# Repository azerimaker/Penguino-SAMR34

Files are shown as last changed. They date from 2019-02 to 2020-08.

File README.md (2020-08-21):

# Penguino Feather LoRa development board
This repo contains all the necessary design and fabrication files for the Penguino radio module and its @Adafruit Father style breakout board. First prototype batch is being sold on my [Tindie](https://www.tindie.com/products/16985/) store.

### Penguino Feather v1.1:
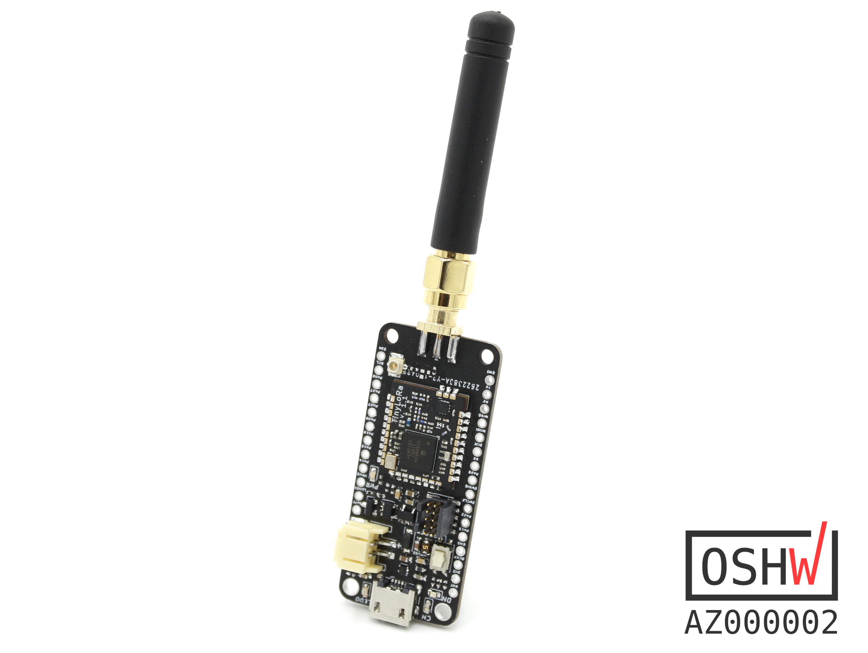
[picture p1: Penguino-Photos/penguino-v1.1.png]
Penguino Feather Breakout v1.1


## Penguino RF Module v1.2 Specs:
- [ATSAMR34J18](http://ww1.microchip.com/downloads/en/DeviceDoc/SAMR34-R35-Low-Power-LoRa-Sub-GHz-SiP-Data-Sheet-DS70005356B.pdf) LoRA System-in-Package (SiP) based RF module
- ARM Cortex M0+ MCU & LoRa Radio
- 256KB Flash, 40 KB RAM
- Power Output: 20.00(dBm) (DS value, real output is not tested)
- Frequency Range: 862 to 1020 MHz (DS values)
- Sleep Current: ~810 nA 
- IO pins: 27
- Module Dimenions: ~16.5x14x2 mm

### Penguino RF Module v1.1:
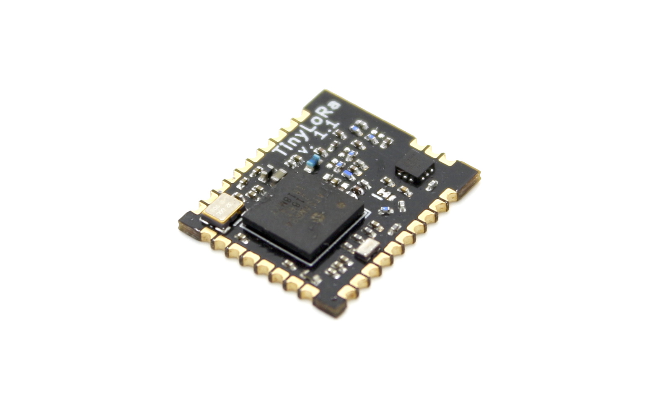
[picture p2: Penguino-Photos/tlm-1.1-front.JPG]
TLM01 v1 front

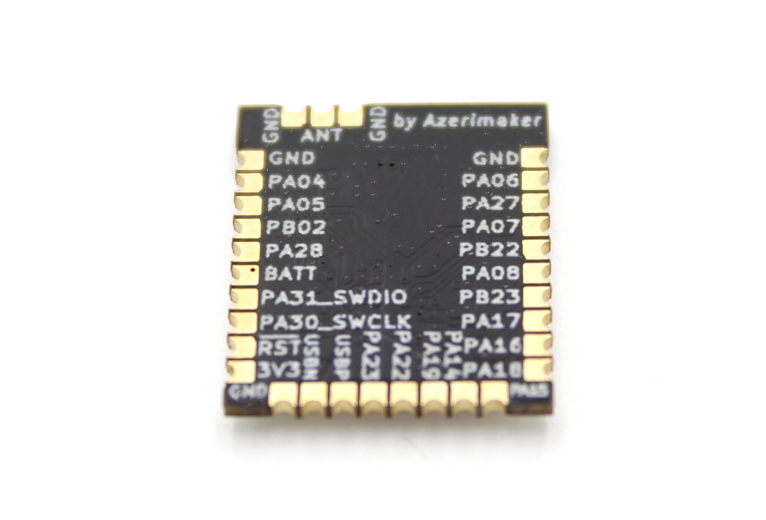
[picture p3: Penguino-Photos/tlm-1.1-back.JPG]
TLM01 v1 back

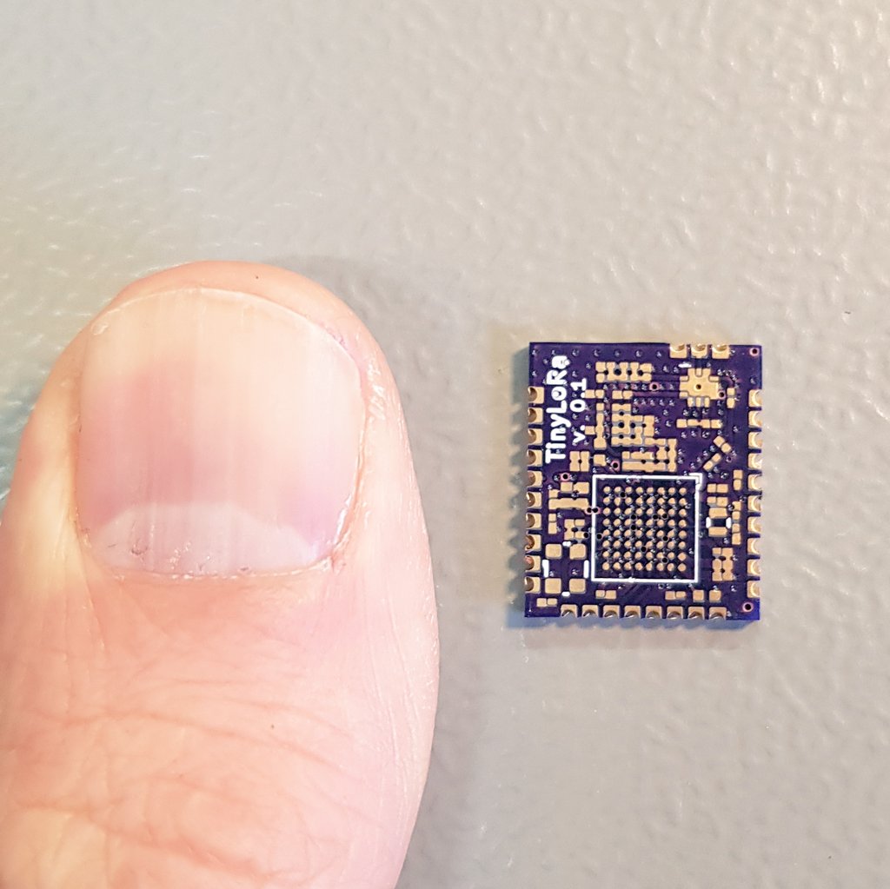
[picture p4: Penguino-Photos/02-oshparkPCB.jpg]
TLM01 v1 OSHpark PCB


### Penguino Feather v1.1 Blinky:
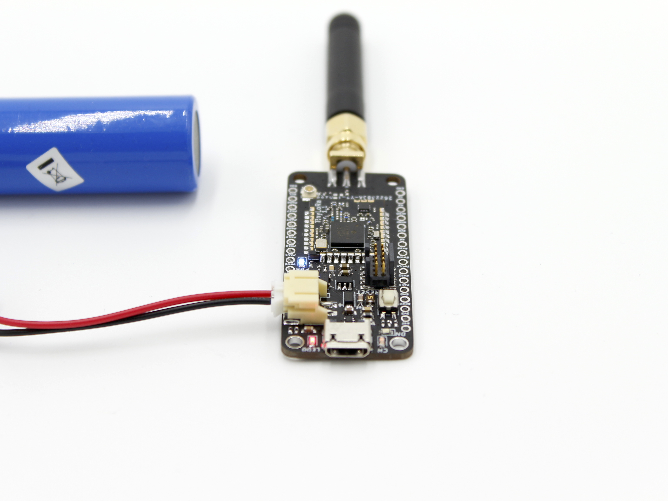
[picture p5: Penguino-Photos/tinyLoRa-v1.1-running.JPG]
TLM01 v1 first prototypes


License:
- Hardware license: CERN-OHL-S v2
- Software license: under MIT unless otherise indicated 
- Documentation license:  CC BY-SA 4.0 International.

________________________________
## Open Source Hardware
This board is an OSHWA approved design: [AZ000002](https://certification.oshwa.org/az000002.html)

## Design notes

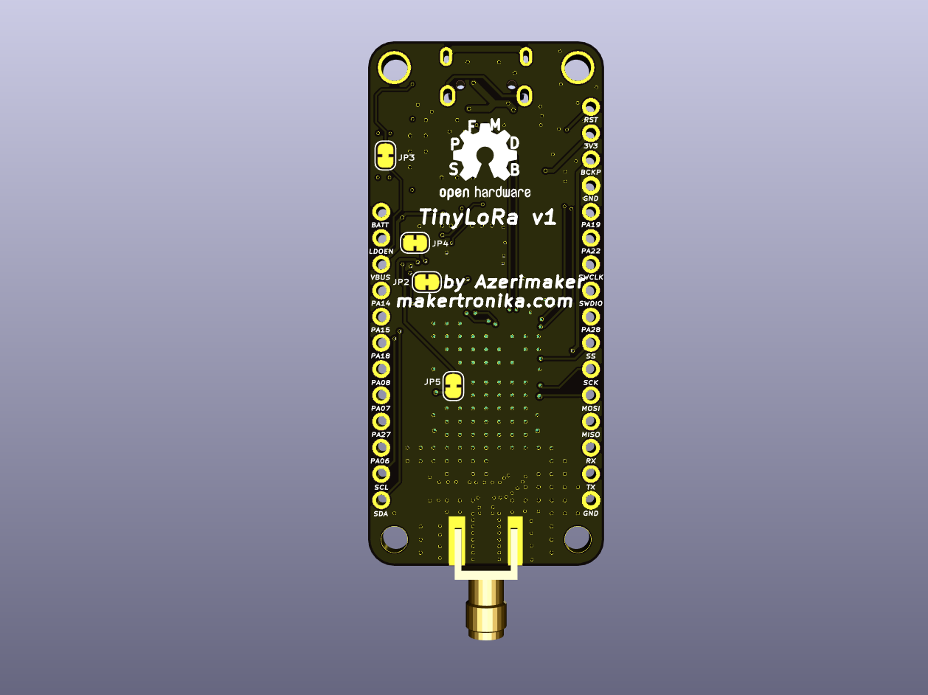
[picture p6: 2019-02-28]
Penguino-Photos/TLM01-breakout-v1-02.png

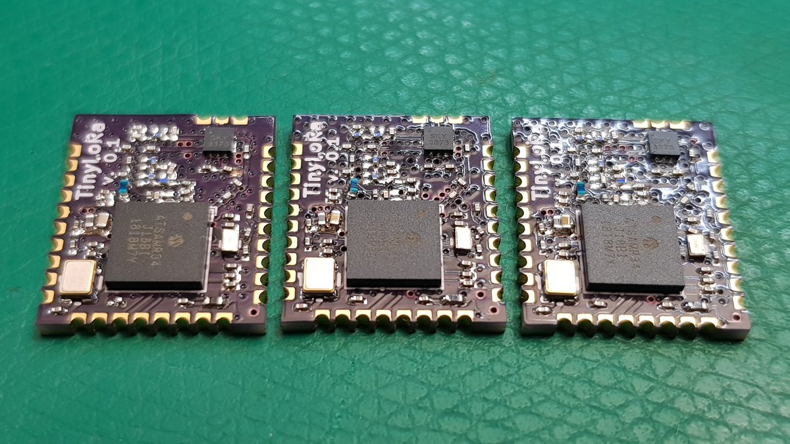
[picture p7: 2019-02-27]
Penguino-Photos/01-firstPrototyes.jpg

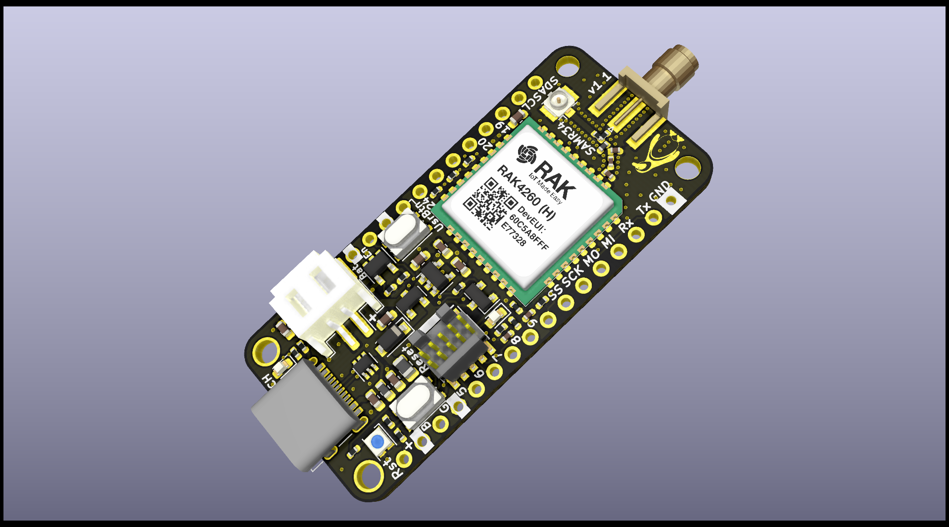
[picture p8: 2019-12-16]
Penguino-Photos/Penguino-Feather-4260-v1.1-3.png

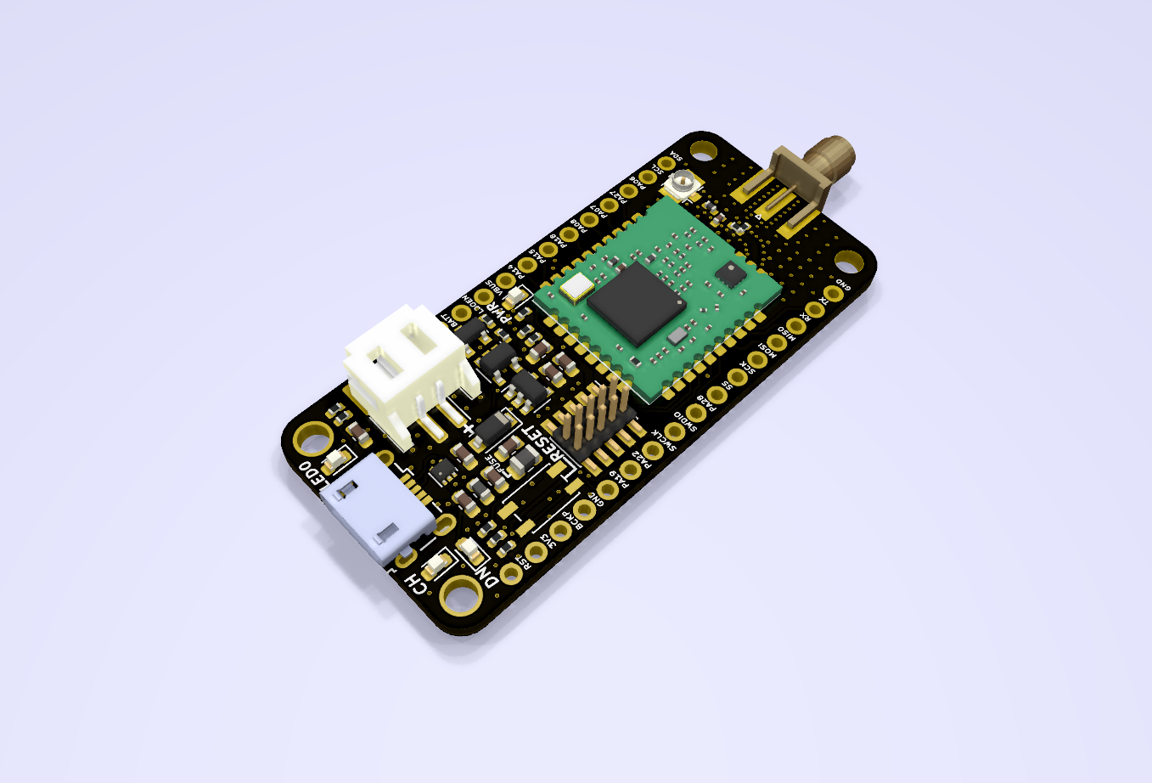
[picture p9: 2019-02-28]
Penguino-Photos/TLM01-breakout-v1-03.png

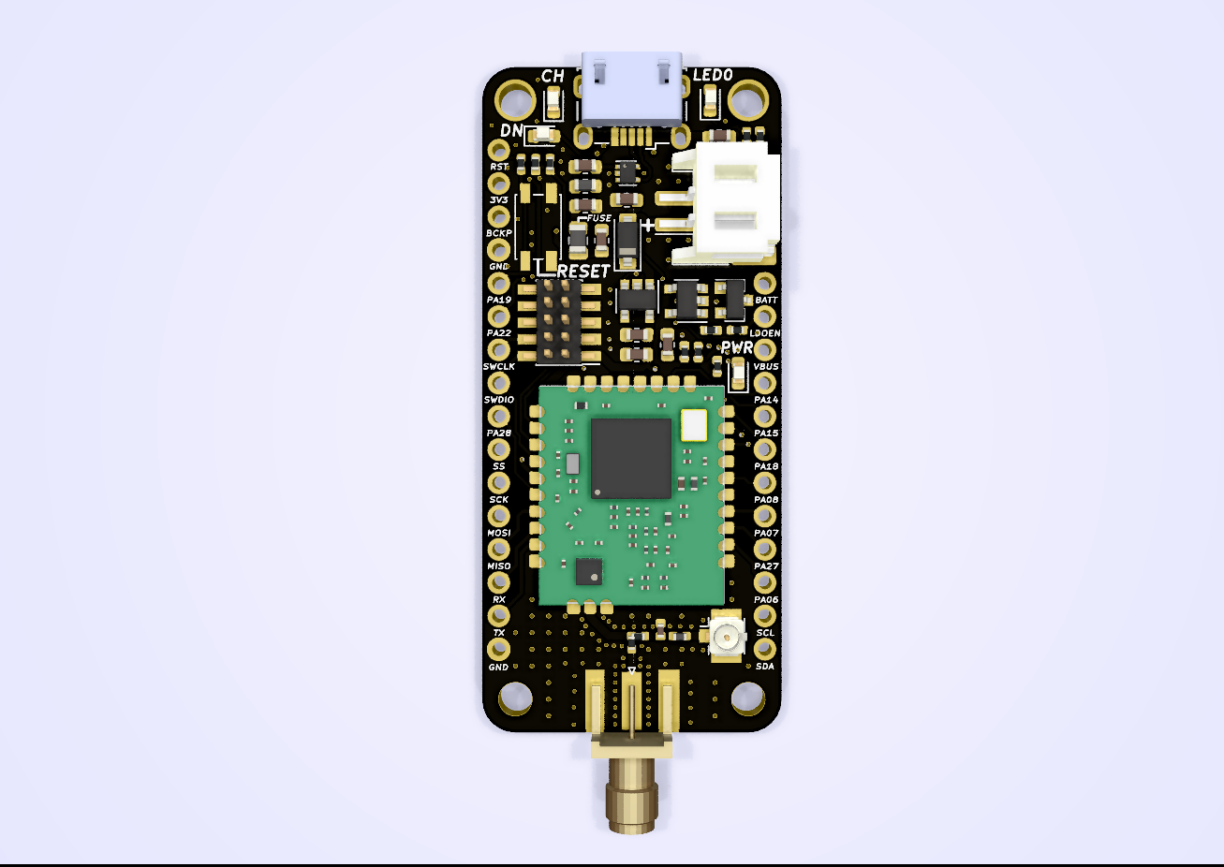
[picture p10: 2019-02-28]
Penguino-Photos/TLM01-breakout-v1-01.png

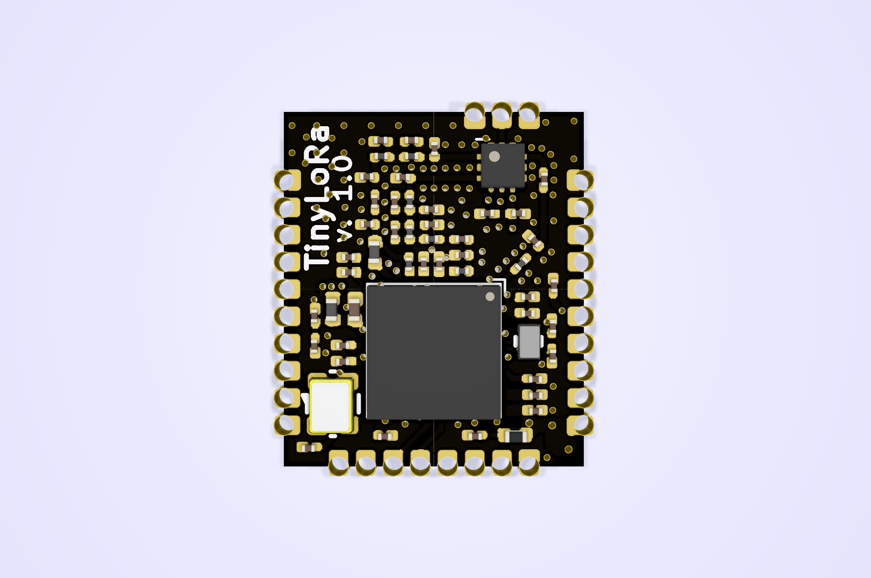
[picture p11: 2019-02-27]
Penguino-Photos/tlm-v1.0-render-front.png

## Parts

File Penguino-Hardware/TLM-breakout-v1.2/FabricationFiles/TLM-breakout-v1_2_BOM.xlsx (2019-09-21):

Name: | TLM01-breakout-v1.2
Date: | 23.06.2019
Tool: | KiCAD Eeschema 5.02
Total Component Count: |  | 34
Unique Component Count: |  | 27
Item # | Ref | Qnty | MPN | Description | Package | URL
1 | C3 C5 | 2 | CL10A106MO8NQNC | 10uF | Capacitor_SMD:C_0603_1608Metric | https://lcsc.com/product-detail/Multilayer-Ceramic-Capacitors-MLCC-SMD-SMT_SAMSUNG_CL10A106MO8NQNC_10uF-106-20-16V_C92487.html
2 | C4 | 1 | CC0603KRX7R8BB105 | 1uF | Capacitor_SMD:C_0603_1608Metric | https://lcsc.com/product-detail/Others_YAGEO-CC0603KRX7R8BB105_C106858.html
3 | C7 C9 | 2 | CC0603KRX7R9BB104 | 100nF | Capacitor_SMD:C_0603_1608Metric | https://lcsc.com/product-detail/Multilayer-Ceramic-Capacitors-MLCC-SMD-SMT_100nF-104-10-50V_C14663.html
4 | C8 C6 | 2 | CC0603KRX7R9BB103 | 10nF | Capacitor_SMD:C_0603_1608Metric | https://lcsc.com/product-detail/Multilayer-Ceramic-Capacitors-MLCC-SMD-SMT_10nF-103-10-50V_C100042.html
5 | D1 | 1 | MBR0520 | MBR0520 | Diode_SMD:D_SOD-123 | https://lcsc.com/product-detail/Schottky-Barrier-Diodes-SBD_Changjiang-Electronics-Tech-CJ-MBR0520_C77335.html
6 | D2 | 1 | 19-217/S2C-AL1M2VY/3T | CH_ORANGE | LED_SMD:LED_0603_1608Metric | https://lcsc.com/product-detail/Others_Everlight-Elec-19-217-S2C-AL1M2VY-3T_C264477.html
7 | D4 | 1 | FC-DA1608BK-470H10 | LED_PWR_BLUE | LED_SMD:LED_0603_1608Metric | https://lcsc.com/product-detail/Light-Emitting-Diodes-LED_Blue-light-SMDLED-80-100mcdatIF-10mA_C84266.html
8 | D5 | 1 | 19-217/R6C-AL1M2VY/3T | LED0_RED | LED_SMD:LED_0603_1608Metric | https://lcsc.com/product-detail/Light-Emitting-Diodes-LED_0603-Red-LED_C72044.html
9 | F1 | 1 | 0805L150SLYR | 1.5A | Fuse_0805_2012Metric | https://lcsc.com/product-detail/Surface-Mount-Fuses_Littelfuse_0805L150SLYR_Littelfuse-0805L150SLYR_C207025.html
10 | FB1 | 1 | BLM18HE152SN1D | BLM18HE152SN1D | Inductor_SMD:L_0603_1608Metric | https://lcsc.com/product-detail/Ferrite-Beads-And-Chips_muRata_BLM18HE152SN1D_1-5KR-25-at100MHz_C82155.html
11 | J1 | 1 | SMA-J-P-H-ST-EM1 | SMA-Edge-Mount | SMA_J_P_X_ST_EM1_EdgeMount | https://www.aliexpress.com/item/-/32953890440.html?spm=a2g0o.cart.0.0.6e6b3c00W25ze0
12 | J2 | 1 | U.FL-R-SMT-1(80) | U.FL-R-SMT-1 | U.FL_Hirose_U.FL-R-SMT-1_Vertical | https://lcsc.com/product-detail/_Hirose_U-FL-R-SMT-1-80_Hirose-HRS-U-FL-R-SMT-1-80_C88374.html
13 | J3 | 1 | S2B-PH-SM4-TB(LF)(SN) | JST_PH | JST_PH_S2B-PH-SM4-TB_1x02-1MP_P2.00mm_Horizontal | https://www.digikey.de/product-detail/de/jst-sales-america-inc/S2B-PH-SM4-TB-LF-SN/455-1749-1-ND/926846
14 | J4 | 1 | C10418 | USB_B_Micro | USB_Micro-B | https://lcsc.com/product-detail/USB-Connectors_Jing-Extension-of-the-Electronic-Co-LCSC-MICRO-USB-5S-B-Type-horns-High-temperature_C10418.html
15 | J5 | 1 | FTSH-105-01-F-DV-K | Cortex_JTAG_SWD_10pin | PinHeader_2x05_P1.27mm_Vertical_SMD | https://www.digikey.de/product-detail/de/samtec-inc/FTSH-105-01-F-DV-K-TR/SAM13160CT-ND/8827915
16 | R10 R11 | 2 | 0402WGF1004TCE | 1M | Resistor_SMD:R_0402_1005Metric | https://lcsc.com/product-detail/Chip-Resistor-Surface-Mount_Uniroyal-Elec-0402WGF1004TCE_C26083.html
17 | R12 | 1 | RC0402JR-073M6L | 3M6 | Resistor_SMD:R_0402_1005Metric | https://lcsc.com/product-detail/Chip-Resistor-Surface-Mount_3-6MR-365-5_C137871.html
18 | L1 R2 | 2 | RC0402JR-070RL | 0R | Resistor_SMD:R_0402_1005Metric | https://lcsc.com/product-detail/Chip-Resistor-Surface-Mount_0R-0R-5_C60485.html
19 | R4 | 1 | RC0402FR-074K7L | 4K7 | Resistor_SMD:R_0402_1005Metric | https://lcsc.com/product-detail/Chip-Resistor-Surface-Mount_4-7KR-4701-1_C105871.html
20 | R5 | 1 | RC0402JR-07100KL | 100K | Resistor_SMD:R_0402_1005Metric | https://lcsc.com/product-detail/Chip-Resistor-Surface-Mount_100KR-104-5_C106234.html
21 | R7 | 1 | RC0402JR-07100RL | 100R | Resistor_SMD:R_0402_1005Metric | https://lcsc.com/product-detail/Chip-Resistor-Surface-Mount_100R-101-5_C106233.html
22 | R9 R8 R6 | 3 | RC0402FR-071K5L | 1K5 | Resistor_SMD:R_0402_1005Metric | https://lcsc.com/product-detail/Chip-Resistor-Surface-Mount_1-5KR-1501-1_C114759.html
23 | SW3 | 1 | SKRPACE010 | RESET | SW_Push_SKRPACE010 | https://lcsc.com/product-detail/Tactile-Switches_ALPS_SKRPACE010_SKRPACE010_C139797.html
24 | U2 | 1 | TP4054 | or MCP73831 LiPo Charger IC | Package_TO_SOT_SMD:SOT-23-5 | https://lcsc.com/product-detail/PMIC-Battery-Management_TP4054_C32574.html
25 | U3 | 1 | MAX809STRG | 2.93V Voltage Supervisor | Package_TO_SOT_SMD:SOT-23 | https://lcsc.com/product-detail/PMIC-Supervisors_TI_TPS3839K33DBZR_TPS3839K33DBZR_C96333.html
26 | U4 | 1 | ME6215C33 | 3.3V LDO | Package_TO_SOT_SMD:SOT-23-5 | https://lcsc.com/product-detail/Low-Dropout-Regulators-LDO_ME6215C33M5G_C84119.html
27 | U5 | 1 | NUP2202W1T2G | NUP2202 | Package_TO_SOT_SMD:SOT-363_SC-70-6 | https://lcsc.com/product-detail/TVS_ON-Semicon_NUP2202W1T2G_ON-Semicon-ON-NUP2202W1T2G_C89322.html

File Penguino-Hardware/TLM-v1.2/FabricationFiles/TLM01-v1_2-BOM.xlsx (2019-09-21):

Name: | TLM01-v1.2 |  |  |  |  |  |  |  | Updates
Date: | 22.07.2019
Tool: | KiCAD Eeschema 5.02
Total Component Count: |  | 48
Unique Component Count: |  | 25
Item # | Ref | Qnty | MPN | Description | Package | Type | URL | ~
1 | C1 | 1 | GRM155R60J106ME15D | 10uF | _0402_1005Metric | SMD | https://www.mouser.de/ProductDetail/?qs=I53XXhTNm8s65u6%252BR3mHqw%3D%3D | ~
3 | C17 | 1 | GRM0335C1H180GA01D | 18pF | _0201_0603Metric | SMD | https://www.mouser.de/ProductDetail/?qs=3ZwS9AhGA%2F5E94CAvJ5D3g%3D%3D | ~
4 | C18 C29 | 2 | GRM0335C1H3R9BA01D | 3.9pF | _0201_0603Metric | SMD | https://www.mouser.de/ProductDetail/?qs=7vGxPDjevFPA4PAcLjuEQA%3D%3D | ~
5 | C19 C21 C32 | 3 | GJM0335C1E3R3BB01D | 3.3pF | _0201_0603Metric | SMD | https://www.mouser.de/ProductDetail/?qs=CDqEb46GNC4YtpMq7%2FbijA%3D%3D | ~
6 | C20 C31 | 2 | GRM0335C1E5R6BA01D | 5.6pF | _0201_0603Metric | SMD | https://www.mouser.de/ProductDetail/?qs=7vGxPDjevFO7ofteVuiOog%3D%3D | ~
7 | C22 | 1 | 250R05L470GV4T | 47pF | _0201_0603Metric | SMD | https://www.mouser.de/ProductDetail/?qs=qF3SSroohZVo%252BRycgwe6NA%3D%3D | ~
8 | C23 | 1 | GJM0335C1E2R7BB01J | 2.7pF | _0201_0603Metric | SMD | https://www.mouser.de/ProductDetail/?qs=YLLXL5qGyDu%252B5BvRK2mndA%3D%3D | ~
9 | C25 | 1 | GRM033R71A472KA01D | 4.7nF | _0201_0603Metric | SMD | https://www.mouser.de/ProductDetail/?qs=7RtWncwVCuzI4WvsbOl%2FQA%3D%3D | ~
10 | C28 | 1 | 02013A220GAT2A | 22pF | _0201_0603Metric | SMD | https://www.mouser.de/ProductDetail/?qs=8uxLZIVza1t02bPvhkkLOQ%3D%3D | ~
11 | C10 C11 C13 C14 C15 C2 C3 C35 C4 C5 C6 C8 C9 | 13 | 02016D104KAT2A | 100nF | _0201_0603Metric | SMD | https://www.mouser.de/ProductDetail/?qs=PN7sAUOUrntlfwxbZzo6OQ%3D%3D | ~
12 | C30 | 1 | GJM0335C1E8R2BB01D | 8.2pF | _0201_0603Metric | SMD | https://www.mouser.de/ProductDetail/?qs=ui%252B2d9lVEI5Br9X%2Fgsfs7g%3D%3D | ~
13 | C12 C33 | 2 | GJM0335C1E4R7CB01D | 4.7pF | _0201_0603Metric | SMD | https://www.mouser.de/ProductDetail/?qs=563MOeNa05LpxJEDDo5HXg%3D%3D | ~
14 | C34 | 1 | GRM033R71C102KA01J | 1nF | _0201_0603Metric | SMD | https://www.mouser.de/ProductDetail/?qs=563MOeNa05Lkaj9jkbLdjg%3D%3D | ~
15 | C36 C37 | 2 | ‎CC0201DRNPO8BN100‎ | 10pF | _0201_0603Metric | SMD | https://www.mouser.de/ProductDetail/?qs=tS%2FAHvPQ%2F57tl3WO6qJY3g%3D%3D | ~
16 | C7 | 1 | GRM0335C1E330JA01D | 33pF | _0201_0603Metric | SMD | https://www.mouser.de/ProductDetail/?qs=3ZwS9AhGA%2F56pkS80K8T0A%3D%3D | ~
17 | FB1 | 1 | BLM15AG121SN1D | Ferrite Beads 120 OHM LOW SPEED | _0402_1005Metric | SMD | https://www.mouser.de/ProductDetail/?qs=0mZ9c%252Bni6FbHnpaodfEgFg%3D%3D | ~
18 | L3 | 1 | LQW15AN2N2C10D | 2.2nH | _0402_1005Metric | SMD | https://www.mouser.de/ProductDetail/?qs=L0gQqYTeSd%252BvMGiveX8TBg%3D%3D | ~
19 | L10 L11 L4 L5 L7 | 5 | LQP03TN10NH02D | 10nH | _0201_0603Metric | SMD | https://www.mouser.de/ProductDetail/?qs=e%252BE4OD6MgMdNOh%2FUxJ4FMA%3D%3D | ~
20 | L6 L8 | 2 | L-05B33NJV6T | 33nH | _0201_0603Metric | SMD | https://www.mouser.de/ProductDetail/?qs=qF3SSroohZUDjNBhhoaXag%3D%3D | ~
21 | L9 | 1 | LQP03TQ11NJ02D | 11nH | _0201_0603Metric | SMD | https://www.mouser.de/ProductDetail/?qs=sEr9WmQGXZZzM50AKPJQwQ%3D%3D | ~
22 | R1 | 1 | RC0402JR-13100KL | 100K | _0402_1005Metric | SMD | https://www.mouser.de/ProductDetail/?qs=fPU49sp6fCKv5x2dIUTdvw%3D%3D | ~
24 | U2 | 1 | ATSAMR34J18BT-I/7JX | ATSAMR34J18BT | TFBGA-64_6.0x6.0_P0.65mm | SMD | https://www.mouser.de/ProductDetail/?qs=PqoDHHvF648Gm3bwnEWPBA%3D%3D | ~
25 | U3 | 1 | SKY13373-460LF | SKY13373-460LF | QFN-12-1EP_3x3mm_P0.5mm | SMD | https://www.mouser.de/ProductDetail/?qs=WMHGlxXAKT%252BCKwFkyhUcUQ%3D%3D | ~
26 | XC1 | 1 | ECS-TXO-2520-33-320-AN-TR | 32MHz TCXO Clipped Sine Wave Oscillator 2.8V ~ 3.3V 4-SMD, No Lead | Oscilator_2.5x2.0 | SMD | https://www.mouser.de/ProductDetail/?qs=KAq9QXcE8HADIhO7CEy%2FJw%3D%3D | ~
27 | Y1 | 1 | ABS05-32.768-kHz-9-T | ABS05-32.768KHZ-9-T | ABS05_32.768KHz Crystal | SMD | https://www.mouser.de/ProductDetail/?qs=Pyu0ZBy%2FIJbsNYnIET1z3A%3D%3D | ~

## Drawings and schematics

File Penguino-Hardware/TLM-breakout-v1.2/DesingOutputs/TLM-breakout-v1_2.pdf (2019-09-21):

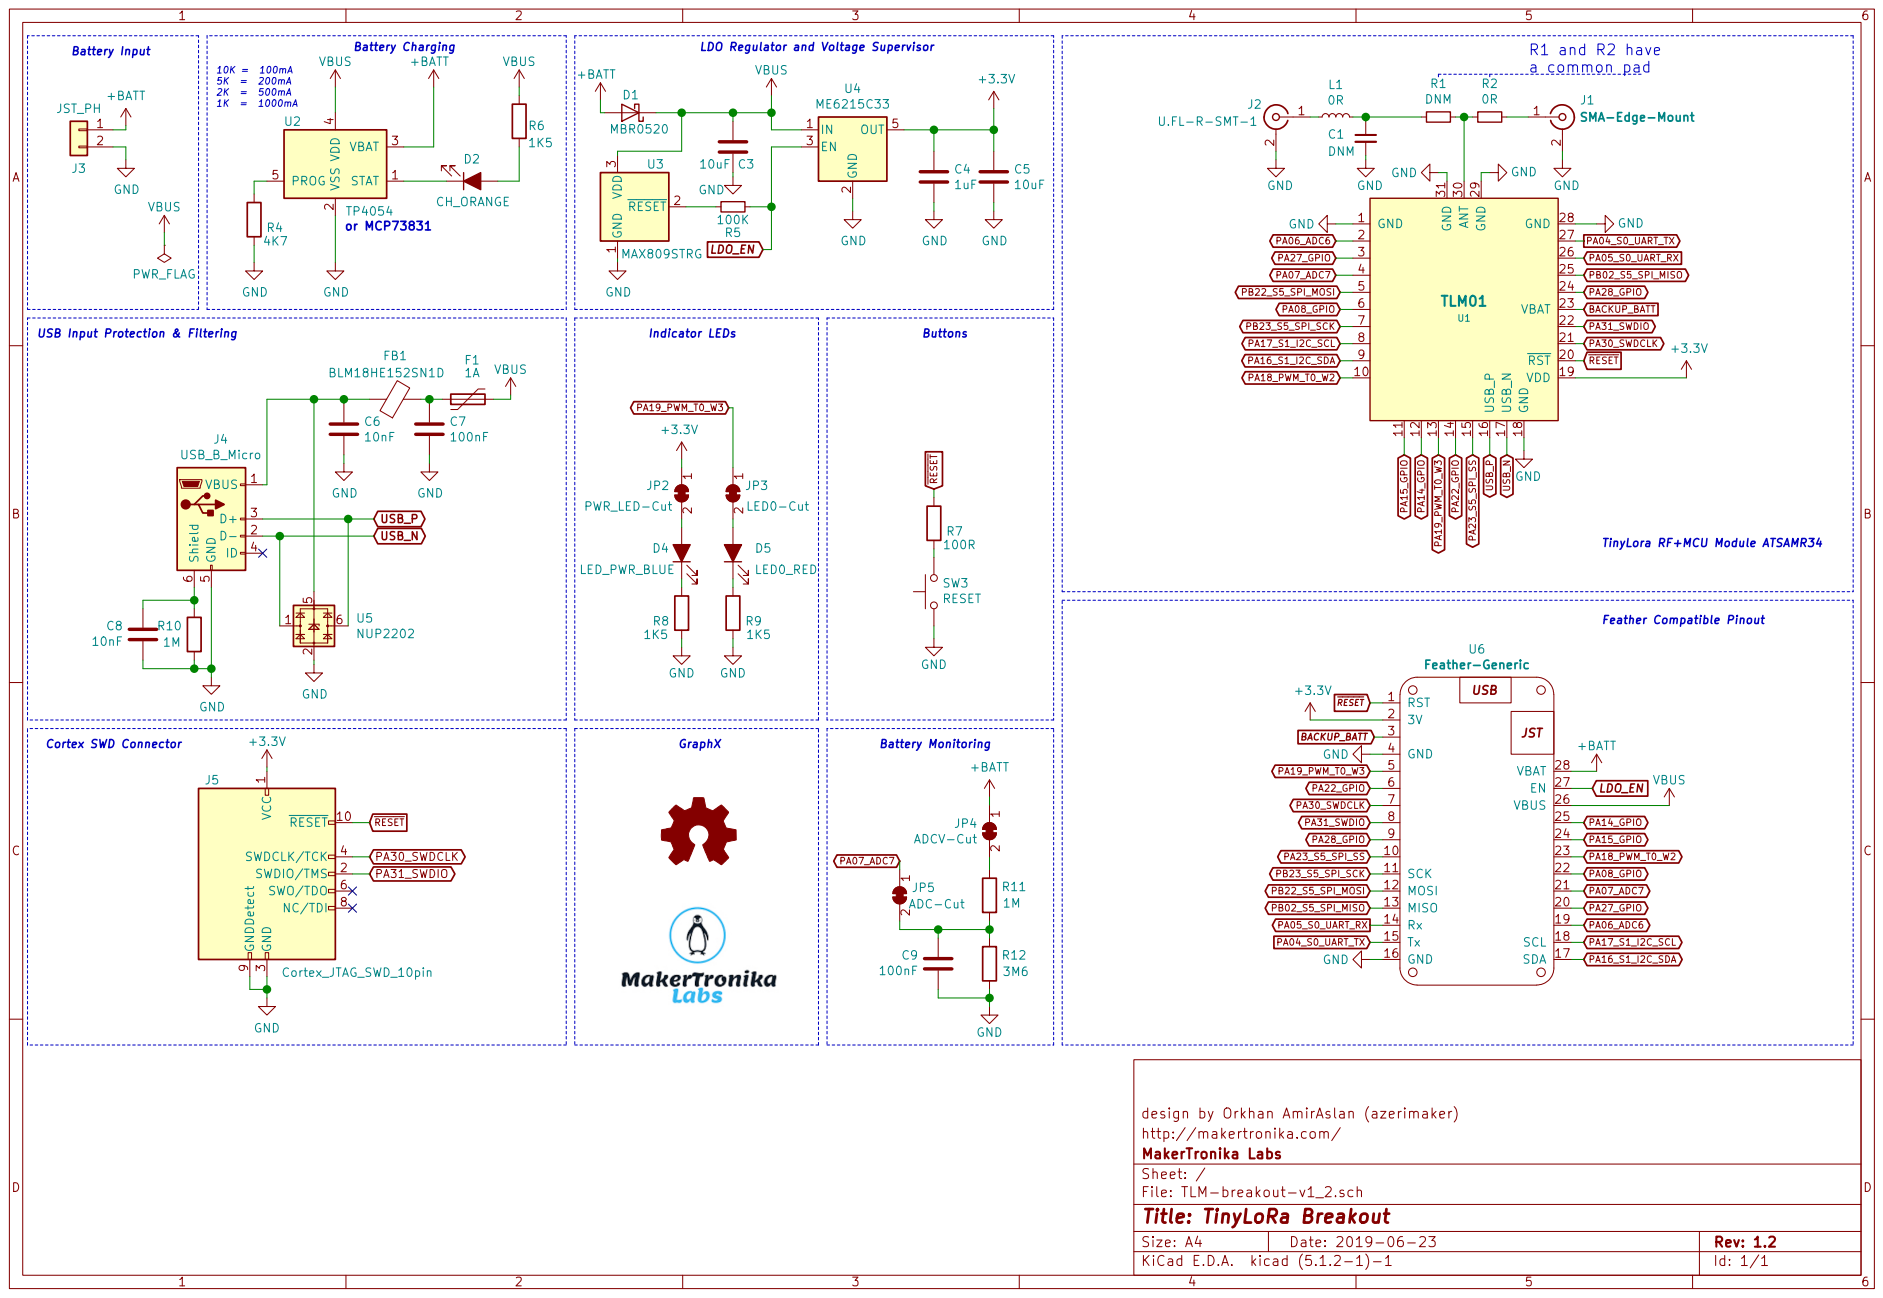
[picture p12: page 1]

2 EN 3 OUT 5 U4 ME6215C33 STAT 1 VSS

1 RESET 10 SWDIO/TMS 2 GND

3 SWDCLK/TCK 4 SWO/TDO 6 NC/TDI 8 GNDDetect 9

design by Orkhan AmirAslan (azerimaker)
http://makertronika.com/
File: TLM-breakout-v1_2.sch Sheet: / MakerTronika Labs

Id: 1/1 Title: TinyLoRa Breakout

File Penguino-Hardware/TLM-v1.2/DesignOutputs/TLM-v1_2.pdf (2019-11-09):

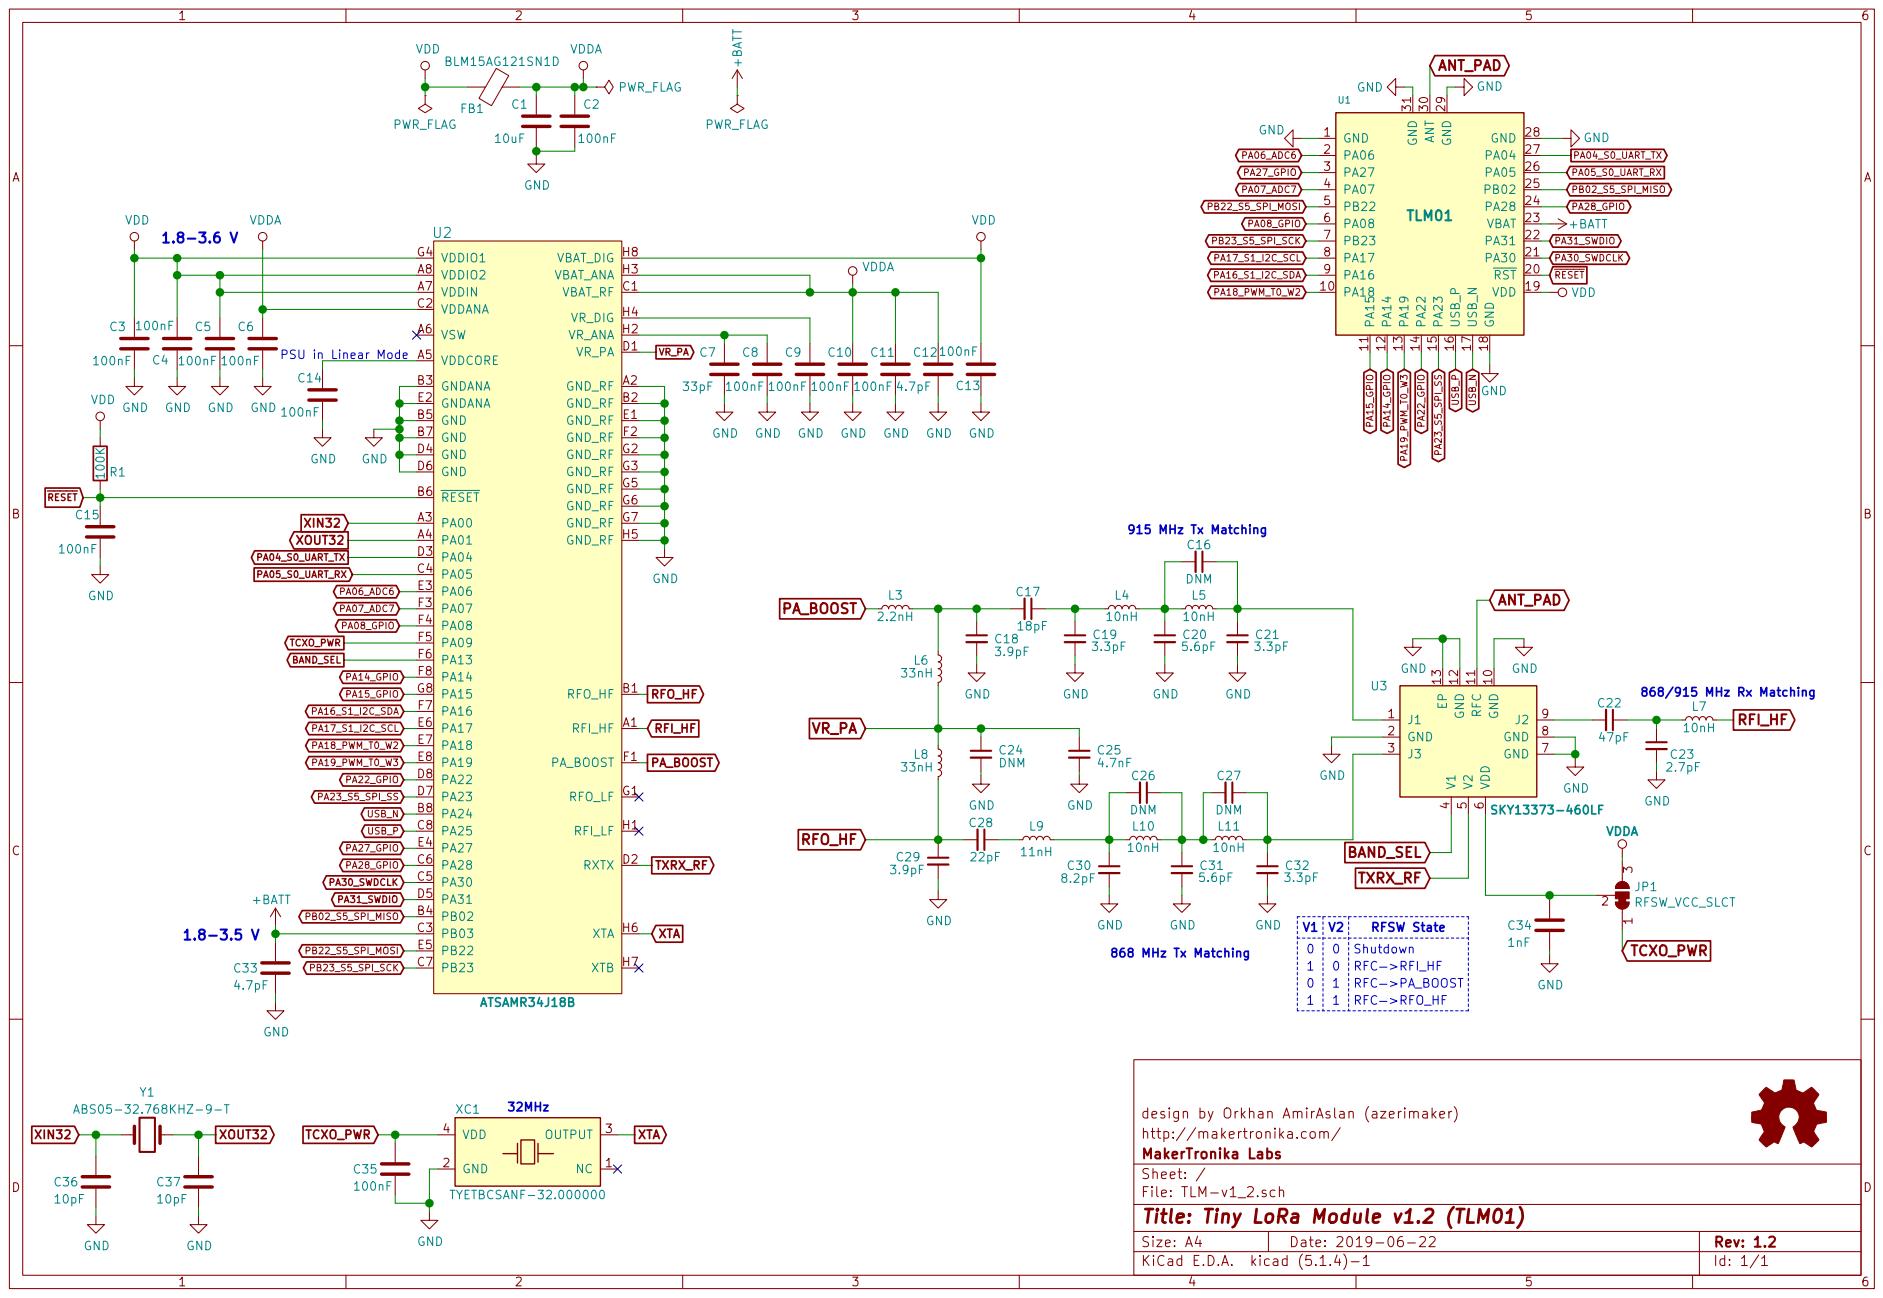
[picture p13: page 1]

design by Orkhan AmirAslan (azerimaker) L6

0 | 0 | Shutdown RFSW State

1 1 | 0 1 1 | RFC>RFO_HF RFC>PA_BOOST RFC>RFI_HF

http://makertronika.com/
File: TLM-v1_2.sch Sheet: / MakerTronika Labs

Id: 1/1 Title: Tiny LoRa Module v1.2 (TLM01)

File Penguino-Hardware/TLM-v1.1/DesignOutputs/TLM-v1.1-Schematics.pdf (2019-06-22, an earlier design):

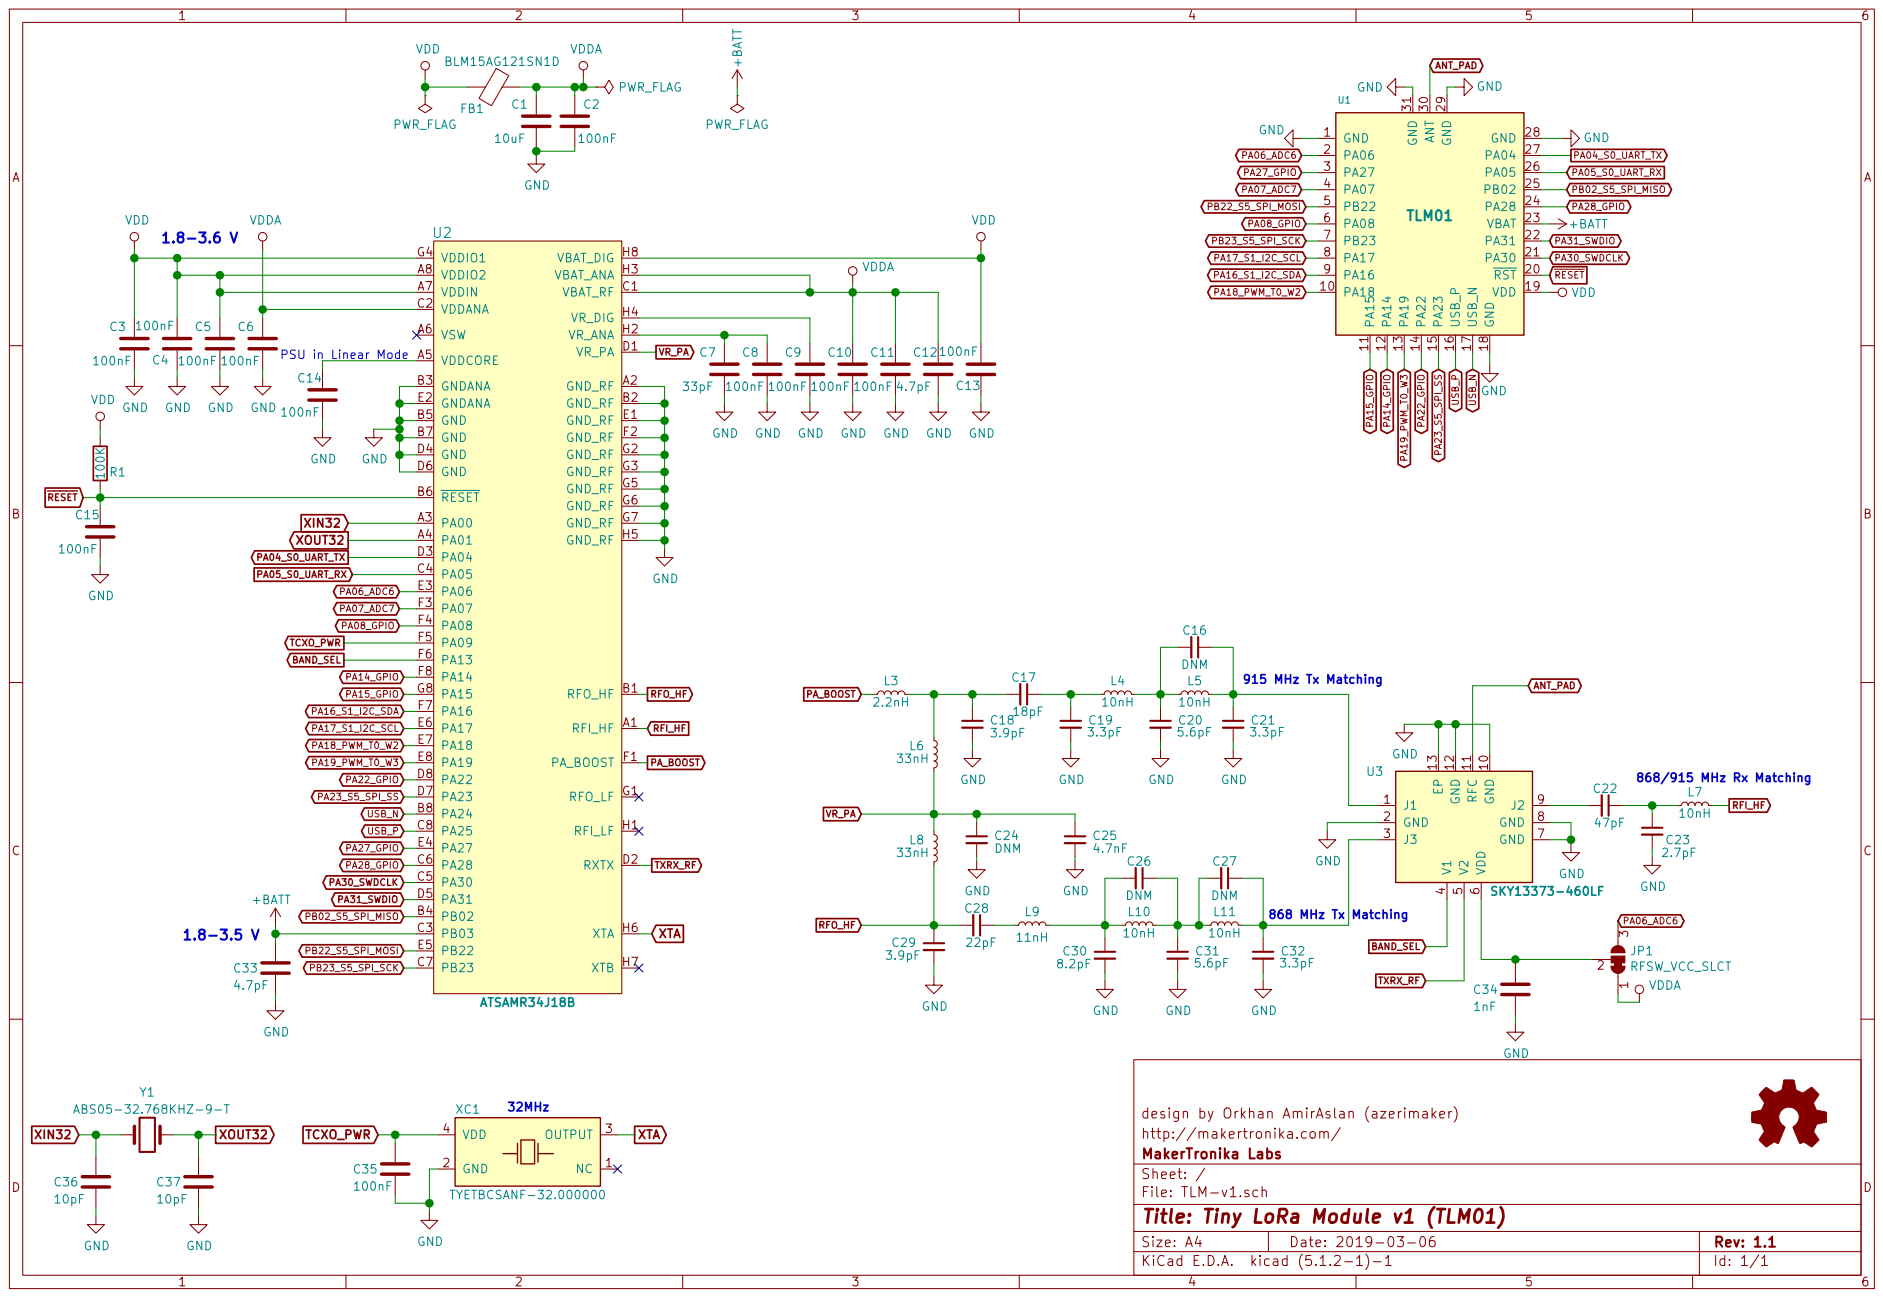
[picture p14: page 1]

PSU in Linear Mode C33

4.7pF GND GND GND GND GND GND GND

http://makertronika.com/
Id: 1/1 Title: Tiny LoRa Module v1 (TLM01) File: TLM-v1.sch Sheet: / MakerTronika Labs

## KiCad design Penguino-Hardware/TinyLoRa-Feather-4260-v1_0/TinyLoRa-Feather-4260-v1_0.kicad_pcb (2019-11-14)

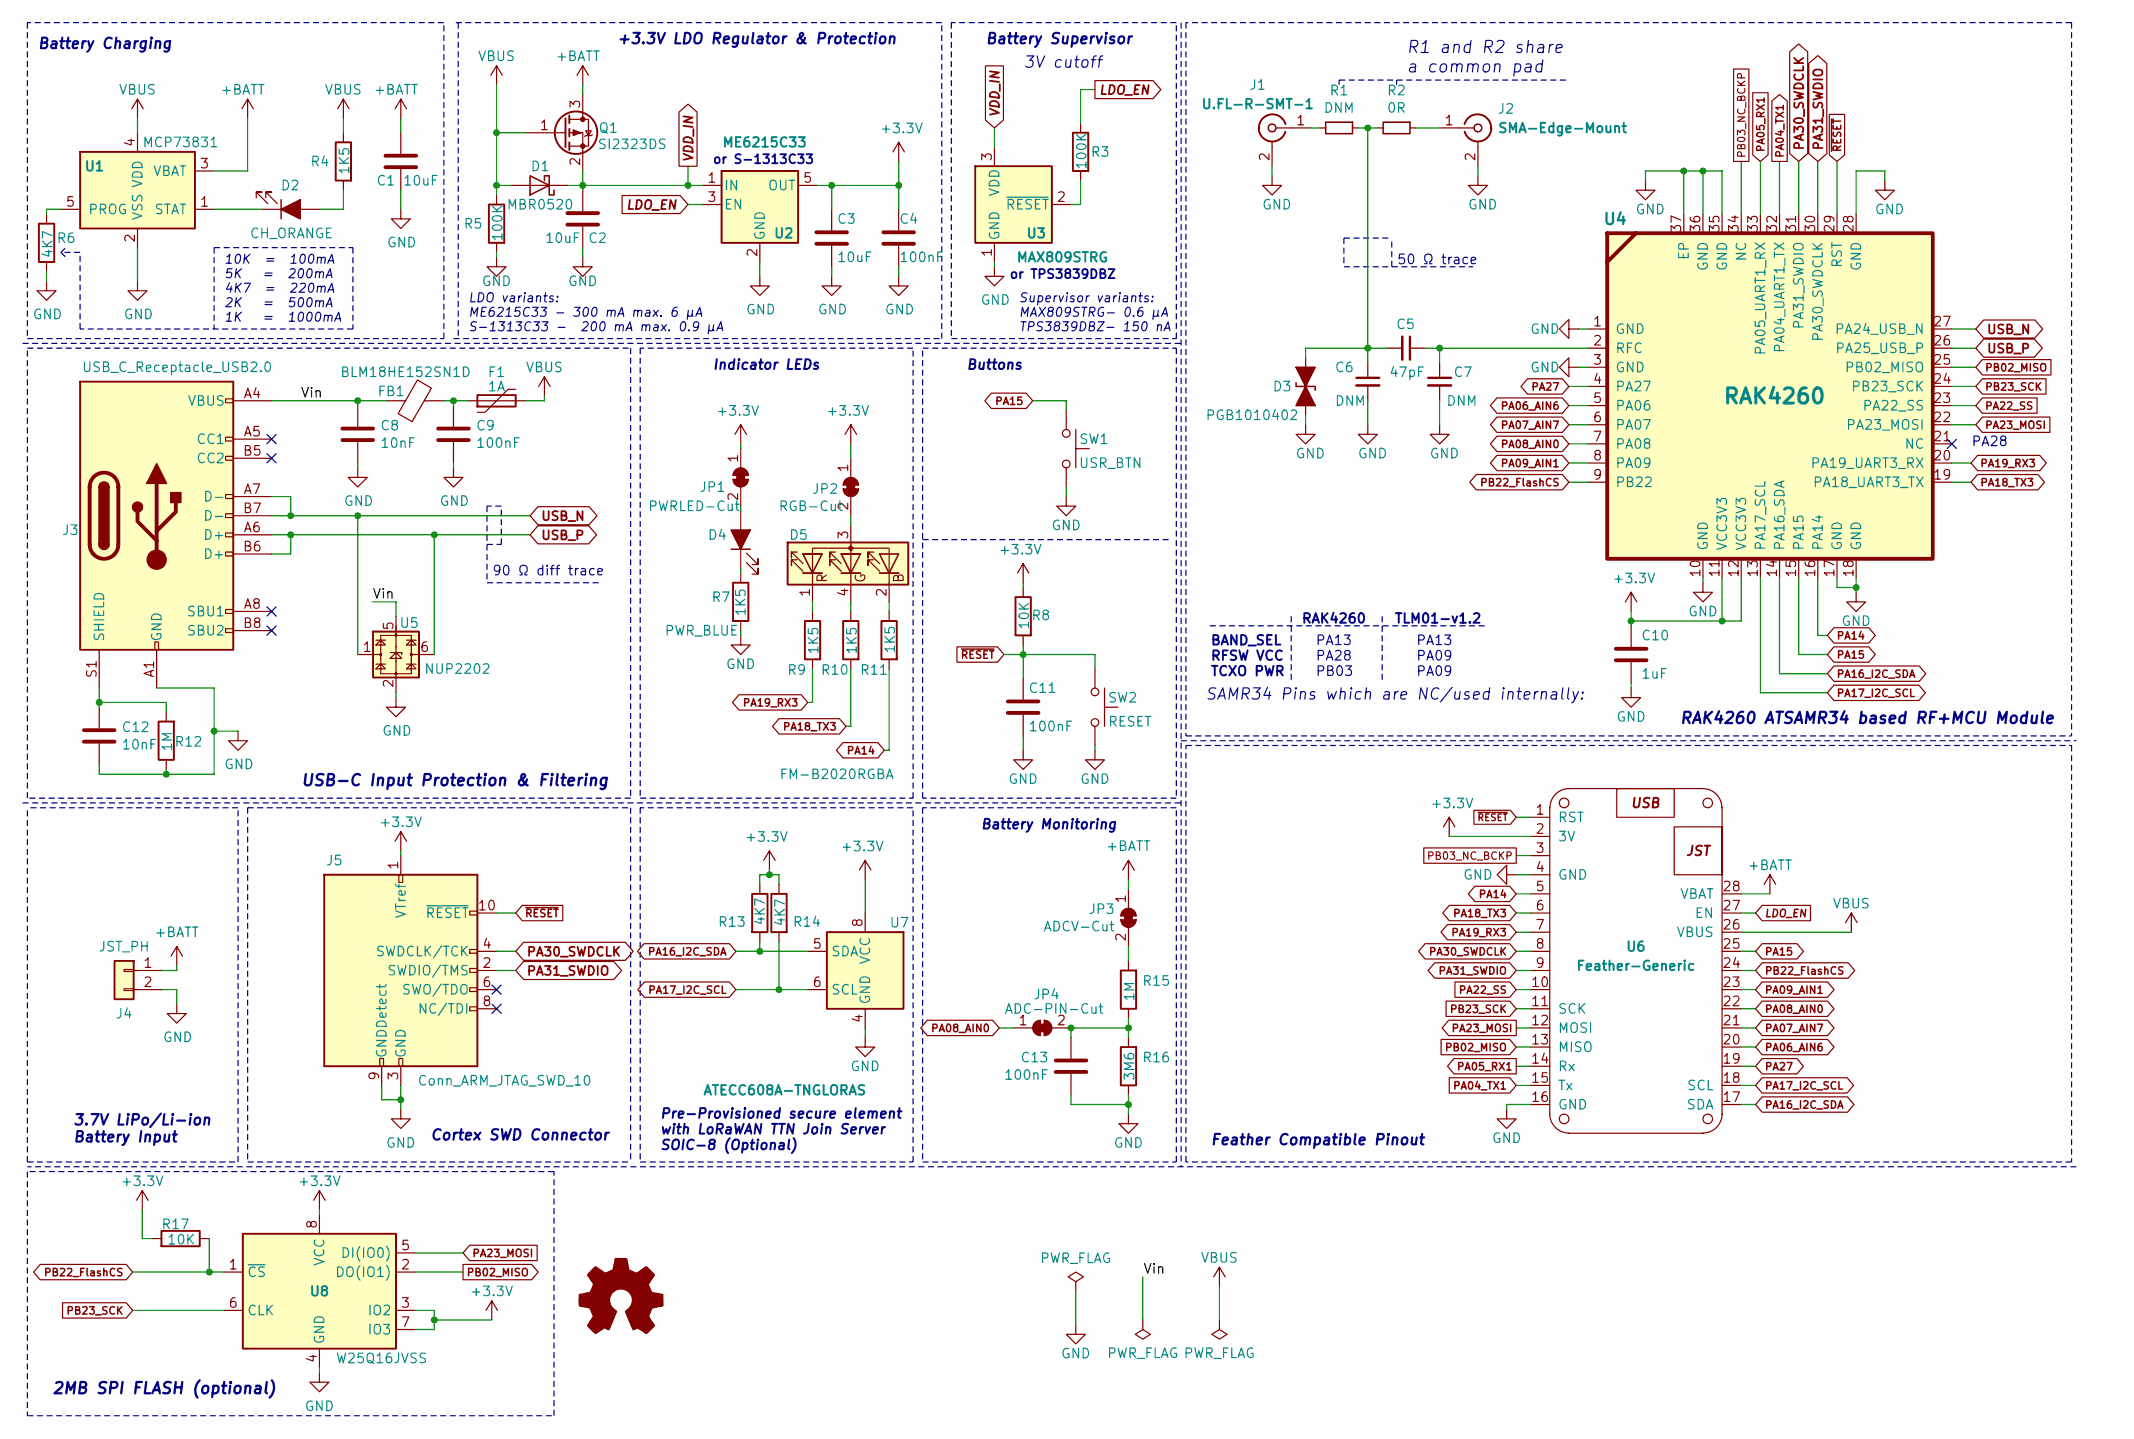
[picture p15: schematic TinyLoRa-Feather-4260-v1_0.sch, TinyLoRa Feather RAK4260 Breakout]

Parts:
C1, C2, C3: 10uF; C_0603_1608Metric
C4, C9: 100nF; C_0603_1608Metric; MPN CC0603KRX7R9BB104
C5: 47pF; C_0402_1005Metric
C6, C7: DNM; C_0402_1005Metric
C8, C12: 10nF; C_0603_1608Metric; MPN CC0603KRX7R9BB103
C10: 1uF; C_0603_1608Metric; MPN CC0603KRX7R8BB105
C11, C13: 100nF; C_0402_1005Metric; MPN CC0603KRX7R9BB104
D1: MBR0520; D_SOD-123; MPN MBR0520
D2: CH_ORANGE; LED_0603_1608Metric
D3: PGB1010402; L_0402_1005Metric; MPN PGB1010402KR
D4: PWR_BLUE; LED_0603_1608Metric
D5: FM-B2020RGBA; LED_Cree-PLCC4_2x2mm_CW; MPN FM-B2020RGBA-HG
F1: 1A; Fuse_0805_2012Metric; MPN 0805L110SLYR
FB1: BLM18HE152SN1D; L_0603_1608Metric; MPN BLM18HE152SN1D
J1: U.FL-R-SMT-1; U.FL_Hirose_U.FL-R-SMT-1_Vertical; MPN U.FL-R-SMT-1(80)
J2: SMA-Edge-Mount; SMA_J_P_X_ST_EM1_EdgeMount; MPN SMA-J-P-H-ST-EM1
J3: USB_C_Receptacle_USB2.0; USB_C_Receptacle_Palconn_UTC16-G; MPN TYPE-C-31-M-12
J4: JST_PH; JST_PH_S2B-PH-SM4-TB_1x02-1MP_P2.00mm_Horizontal; MPN S2B-PH-SM4-TB(LF)(SN)
J5: Conn_ARM_JTAG_SWD_10; PinHeader_2x05_P1.27mm_Vertical_SMD
JP1: PWRLED-Cut; SolderJumper-2_P1.3mm_Bridged_RoundedPad1.0x1.5mm
JP2: RGB-Cut; SolderJumper-2_P1.3mm_Bridged_RoundedPad1.0x1.5mm
JP3: ADCV-Cut; SolderJumper-2_P1.3mm_Bridged_RoundedPad1.0x1.5mm
JP4: ADC-PIN-Cut; SolderJumper-2_P1.3mm_Bridged_RoundedPad1.0x1.5mm
Q1: SI2323DS; SOT-23; MPN SI2323DS-T1-E3
R1: DNM; R_0402_1005Metric
R2: 0R; R_0402_1005Metric
R3, R5: 100K; R_0402_1005Metric
R4, R7, R9, R10, R11: 1K5; R_0402_1005Metric
R6, R13, R14: 4K7; R_0402_1005Metric
R8, R17: 10K; R_0402_1005Metric
R12, R15: 1M; R_0402_1005Metric
R16: 3M6; R_0402_1005Metric; MPN RC0402JR-073M6L
SW1: USR_BTN; SW_Push_SKRPACE010; MPN SKRPACE010
SW2: RESET; SW_Push_SKRPACE010; MPN SKRPACE010
U1: MCP73831; SOT-23-5; MPN MCP73831-2-OT
U2: ME6215C33; SOT-23-5; MPN ME6215C33
U3: MAX809STRG; SOT-23; MPN MAX809STRG
U4: RAK4260; RAK4260-footprint_w_solder_paste
U5: NUP2202; SOT-363_SC-70-6; MPN NUP2202W1T2G
U6: Feather-Generic
U7: ATECC608A-TNGLORAS; SOIC-8_3.9x4.9mm_P1.27mm; MPN ATECC608A-TNGLORAS-B
U8: W25Q16JVSS; SOIC-8_5.23x5.23mm_P1.27mm

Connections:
+3V3: C3.1, C4.1, C10.1, J5.1 (VTref), JP1.1 (A), JP2.1 (A), R8.1, R13.1, R14.1, R17.2, U2.5 (OUT), U4.11 (VCC3V3), U4.12 (VCC3V3), U6.2 (3V), U7.8 (VCC), U8.3 (IO2), U8.7 (IO3), U8.8 (VCC)
+BATT: C1.1, J4.1, JP3.1 (A), Q1.3 (D), U1.3 (VBAT), U6.28 (VBAT)
/Vin: C8.1, FB1.1, J3.A4 (VBUS), J3.A9 (VBUS), J3.B4 (VBUS), J3.B9 (VBUS), U5.5
GND: C1.2, C2.2, C3.2, C4.2, C6.2, C7.2, C8.2, C9.2, C10.2, C11.2, C12.1, C13.1, D3.2 (A2), J1.2 (Ext), J2.2 (Ext), J3.A1 (GND), J3.A12 (GND), J3.B1 (GND), J3.B12 (GND), J4.2, J5.3 (GND), J5.5 (GND), J5.9 (GNDDetect), R5.2, R6.2, R7.2, R12.1, R16.1, SW1.1, SW2.1, U1.2 (VSS), U2.2 (GND), U3.1 (GND), U4.1 (GND), U4.3 (GND), U4.10 (GND), U4.17 (GND), U4.18 (GND), U4.28 (GND), U4.35 (GND), U4.36 (GND), U4.37 (EP), U5.2, U6.4 (GND), U6.16 (GND), U7.4 (GND), U8.4 (GND)
LDO_EN: R3.1, U2.3 (EN), U6.27 (EN)
unnamed: C5.1, C7.1, U4.2 (RFC)
unnamed: C5.2, C6.1, D3.1 (A1), R1.1, R2.2
unnamed: C9.1, F1.1, FB1.2
unnamed: C12.2, J3.S1 (SHIELD), R12.2
unnamed: C13.2, JP4.2 (B), R15.1, R16.2
unnamed: D2.1 (K), U1.1 (STAT)
unnamed: D2.2 (A), R4.2
unnamed: D4.1 (K), R7.1
unnamed: D4.2 (A), JP1.2 (B)
unnamed: D5.1 (RK), R9.1
unnamed: D5.2 (BK), R11.1
unnamed: D5.3 (A), JP2.2 (B)
unnamed: D5.4 (GK), R10.1
unnamed: J1.1 (In), R1.2
unnamed: J2.1 (In), R2.1
unnamed: JP3.2 (B), R15.2
unnamed: R3.2, U3.2 (~RESET)
unnamed: R6.1, U1.5 (PROG)
PA04_TX1: U4.32 (PA04_UART1_TX), U6.15 (Tx)
PA05_RX1: U4.33 (PA05_UART1_RX), U6.14 (Rx)
PA06_AIN6: U4.5 (PA06), U6.20
PA07_AIN7: U4.6 (PA07), U6.21
PA08_AIN0: JP4.1 (A), U4.7 (PA08), U6.22
PA09_AIN1: U4.8 (PA09), U6.23
PA14: R11.2, U4.16 (PA14), U6.5
PA15: SW1.2, U4.15 (PA15), U6.25
PA16_I2C_SDA: R13.2, U4.14 (PA16_SDA), U6.17 (SDA), U7.5 (SDA)
PA17_I2C_SCL: R14.2, U4.13 (PA17_SCL), U6.18 (SCL), U7.6 (SCL)
PA18_TX3: R10.2, U4.19 (PA18_UART3_TX), U6.6
PA19_RX3: R9.2, U4.20 (PA19_UART3_RX), U6.7
PA22_SS: U4.23 (PA22_SS), U6.10
PA23_MOSI: U4.22 (PA23_MOSI), U6.12 (MOSI), U8.5 (DI(IO0))
PA27: U4.4 (PA27), U6.19
PA30_SWDCLK: J5.4 (SWDCLK/TCK), U4.31 (PA31_SWDIO), U6.8
PA31_SWDIO: J5.2 (SWDIO/TMS), U4.30 (PA30_SWDCLK), U6.9
PB02_MISO: U4.25 (PB02_MISO), U6.13 (MISO), U8.2 (DO(IO1))
PB03_NC_BCKP: U4.34 (NC), U6.3
PB22_FlashCS: R17.1, U4.9 (PB22), U6.24, U8.1 (~CS)
PB23_SCK: U4.24 (PB23_SCK), U6.11 (SCK), U8.6 (CLK)
USB_N: J3.A7 (D-), J3.B7 (D-), U4.27 (PA24_USB_N), U5.1
USB_P: J3.A6 (D+), J3.B6 (D+), U4.26 (PA25_USB_P), U5.6
VBUS: D1.2 (A), F1.2, Q1.1 (G), R4.1, R5.1, U1.4 (VDD), U6.26 (VBUS)
VDD_IN: C2.1, D1.1 (K), Q1.2 (S), U2.1 (IN), U3.3 (VDD)
~RESET: C11.1, J5.10 (~RESET~), R8.2, SW2.2, U4.29 (RST), U6.1 (RST)

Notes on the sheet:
10K = 100mA 5K = 200mA 4K7 = 220mA 2K = 500mA 1K = 1000mA
3.7V LiPo/Li-ion Battery Input
Battery Charging
USB-C Input Protection & Filtering
Indicator LEDs
RAK4260 ATSAMR34 based RF+MCU Module
Feather Compatible Pinout
Battery Monitoring
R1 and R2 share a common pad
Cortex SWD Connector
90 Ω diff trace
50 Ω trace
SAMR34 Pins which are NC/used internally:
PA28
Pre-Provisioned secure element with LoRaWAN TTN Join Server SOIC-8 (Optional)
Buttons
+3.3V LDO Regulator & Protection
Battery Supervisor
LDO variants: ME6215C33 - 300 mA max. 6 μA S-1313C33 - 200 mA max. 0.9 μA
3V cutoff
or TPS3839DBZ
or S-1313C33
Supervisor variants: MAX809STRG- 0.6 μA TPS3839DBZ- 150 nA
2MB SPI FLASH (optional)
BAND_SEL RFSW VCC TCXO PWR
PA13 PA28 PB03
PA13 PA09 PA09
RAK4260 TLM01-v1.2

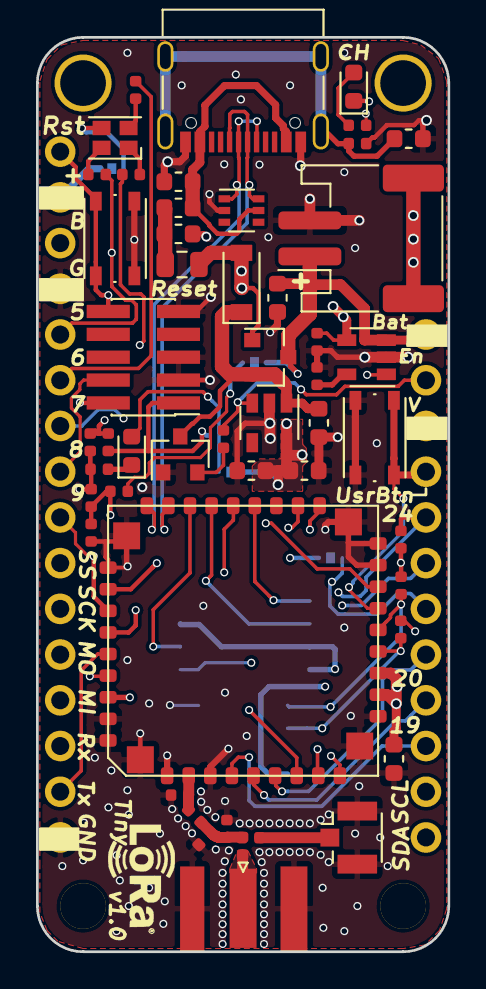
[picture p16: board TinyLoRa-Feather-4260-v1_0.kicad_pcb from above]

Board: 4 copper layers, 22.9 x 50.8 mm, 57 parts (0 on the bottom side), 49 nets.

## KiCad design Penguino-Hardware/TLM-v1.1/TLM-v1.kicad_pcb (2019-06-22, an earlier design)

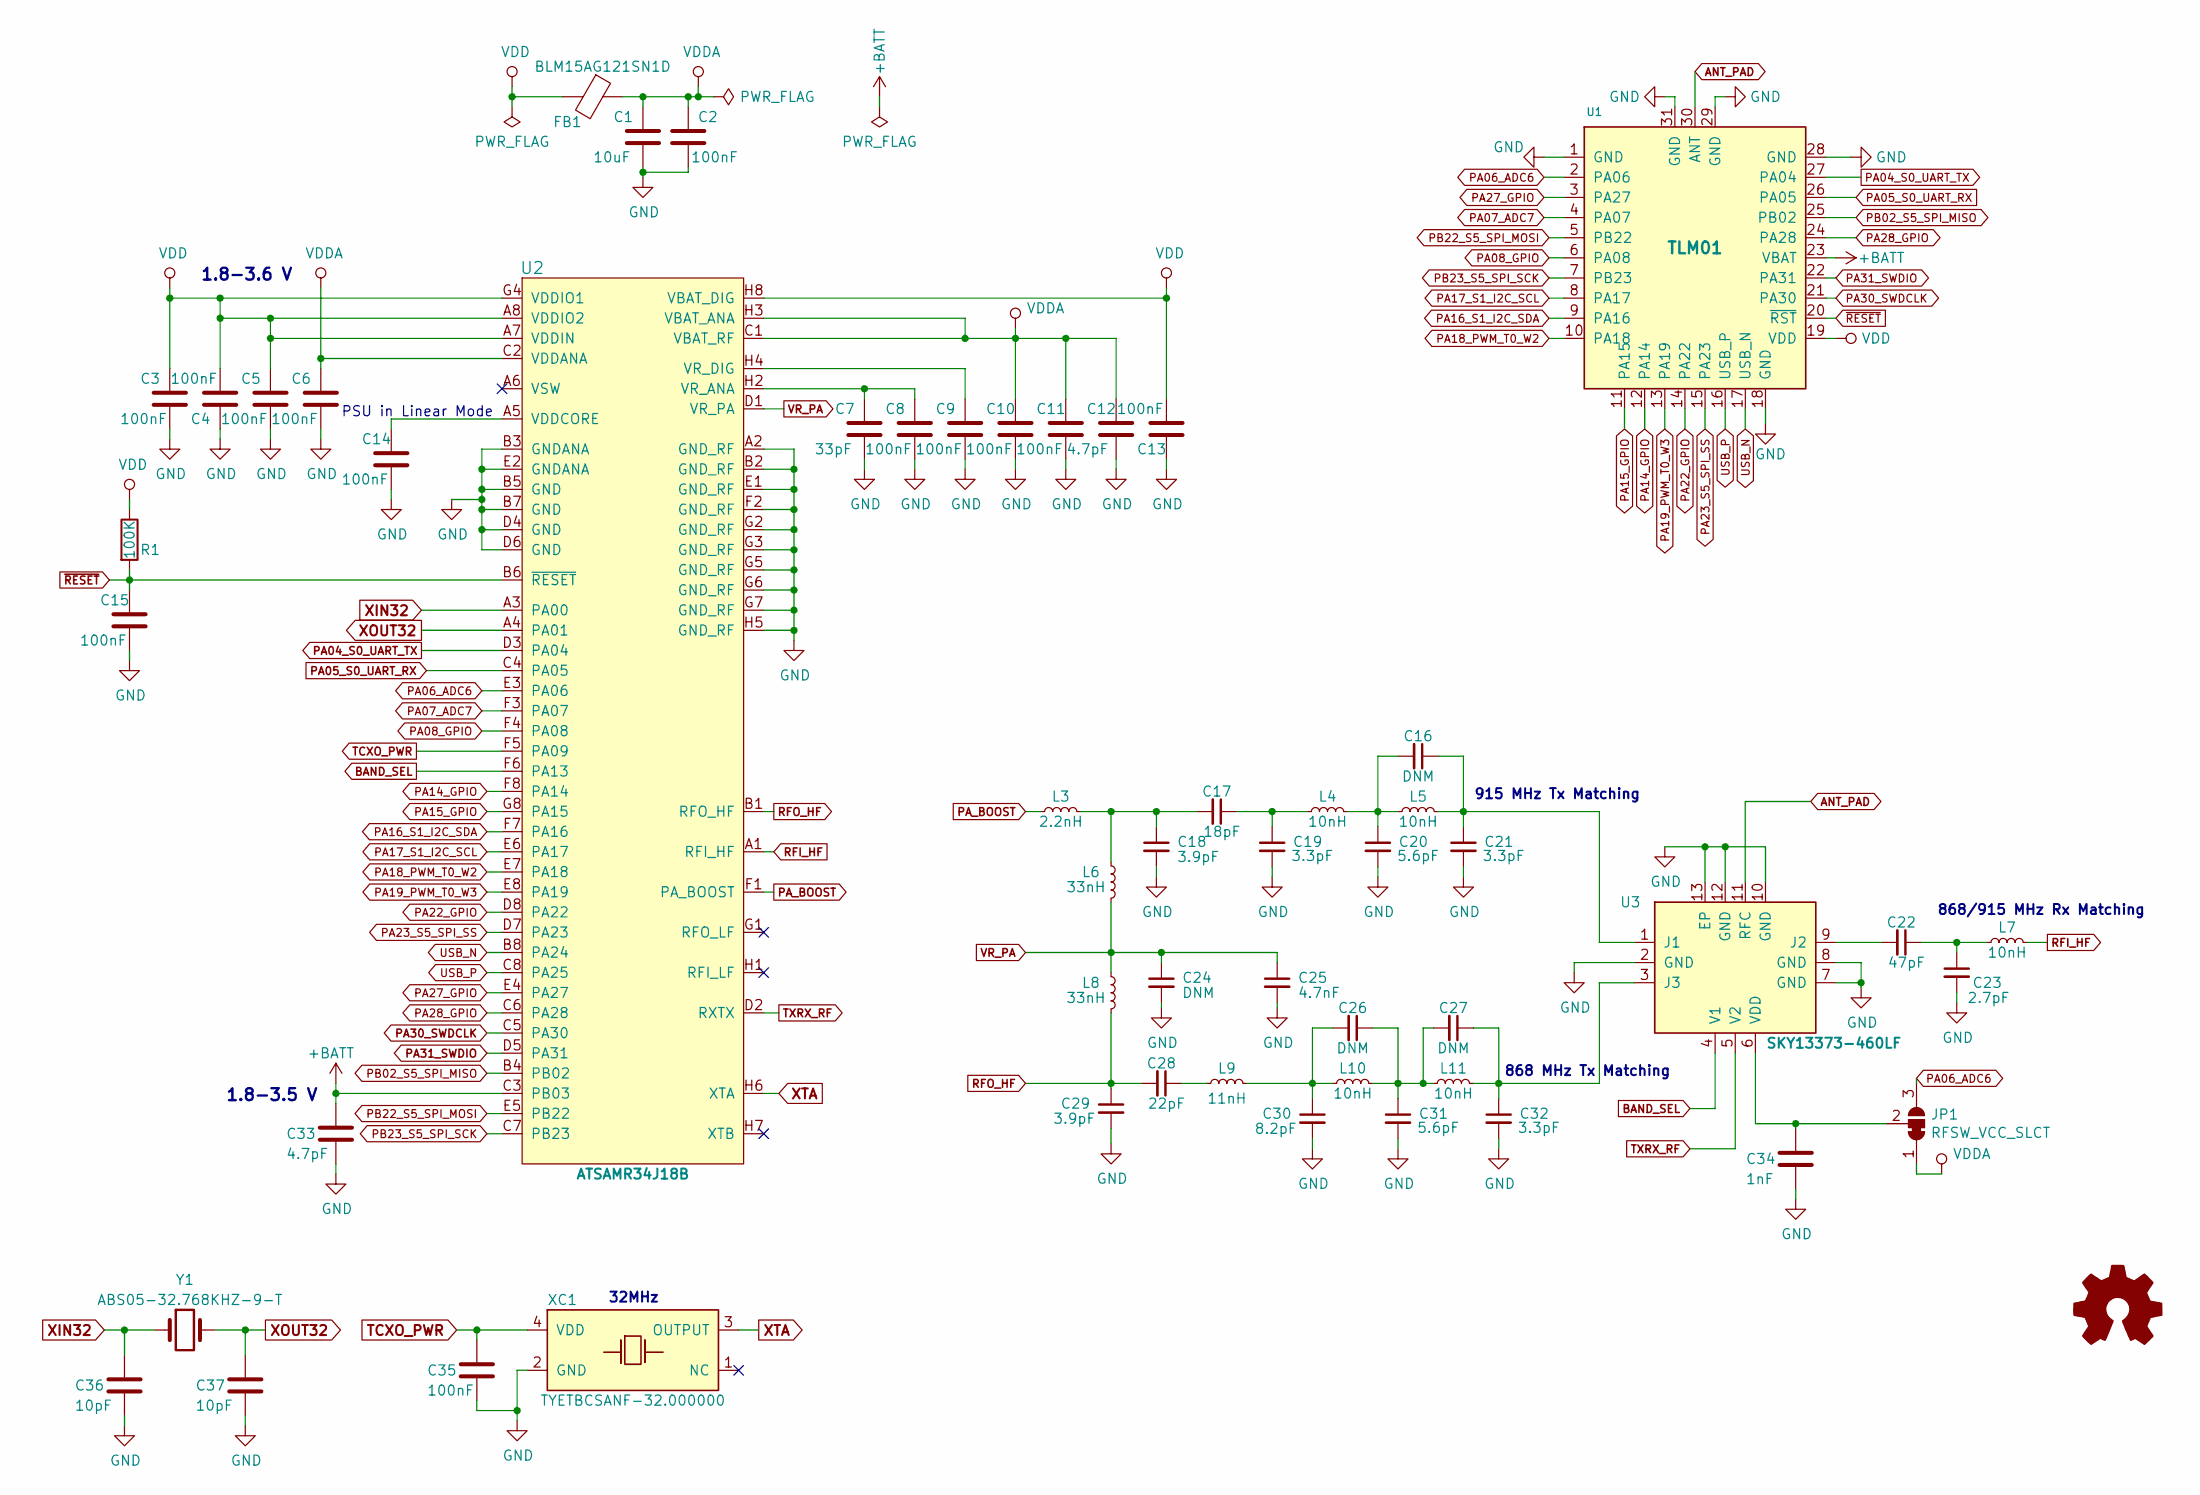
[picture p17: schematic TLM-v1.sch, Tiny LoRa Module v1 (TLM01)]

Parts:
C1: 10uF; C_0402_1005Metric
C2, C3, C4, C5, C6, C8, C9, C10, C11, C13, C14, C15, C35: 100nF; C_0201_0603Metric
C7: 33pF; C_0201_0603Metric
C12, C33: 4.7pF; C_0201_0603Metric
C16, C24, C26, C27: DNM; C_0201_0603Metric
C17: 18pF; C_0201_0603Metric
C18, C29: 3.9pF; C_0201_0603Metric
C19, C21, C32: 3.3pF; C_0201_0603Metric
C20, C31: 5.6pF; C_0201_0603Metric
C22: 47pF; C_0201_0603Metric
C23: 2.7pF; C_0201_0603Metric
C25: 4.7nF; C_0201_0603Metric
C28: 22pF; C_0201_0603Metric
C30: 8.2pF; C_0201_0603Metric
C34: 1nF; C_0201_0603Metric
C36, C37: 10pF; C_0201_0603Metric
FB1: BLM15AG121SN1D; L_0402_1005Metric
JP1: RFSW_VCC_SLCT; JP_NO_NC
L3: 2.2nH; L_0402_1005Metric
L4, L5, L7, L10, L11: 10nH; L_0201_0603Metric
L6, L8: 33nH; L_0201_0603Metric
L9: 11nH; L_0201_0603Metric
R1: 100K; R_0402_1005Metric
U1: TLM01; TLM-01-module
U2: ATSAMR34J18B; TFBGA-64_6.0x6.0mm_Layout8x8_P0.65mm
U3: SKY13373-460LF; QFN-12-1EP_3x3mm_P0.5mm_EP1.65x1.65mm
XC1: TYETBCSANF-32.000000; Oscilator_2.5x2.0
Y1: ABS05-32.768KHZ-9-T; ABS05_32.768KHz Crystal

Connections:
+BATT: C33.1, U1.23 (VBAT), U2.C3 (PB03)
ANT_PAD: U1.30 (ANT), U3.11 (RFC)
BAND_SEL: U2.F6 (PA13), U3.4 (V1)
GND: C1.2, C2.2, C3.2, C4.1, C5.2, C6.2, C7.2, C8.2, C9.2, C10.2, C11.2, C12.2, C13.1, C14.2, C15.2, C18.2, C19.2, C20.2, C21.2, C23.2, C24.2, C25.2, C29.2, C30.2, C31.2, C32.2, C33.2, C34.2, C35.2, C36.2, C37.2, U1.1 (GND), U1.18 (GND), U1.28 (GND), U1.29 (GND), U1.31 (GND), U2.A2 (GND_RF), U2.B2 (GND_RF), U2.B3 (GNDANA), U2.B5 (GND), U2.B7 (GND), U2.D4 (GND), U2.D6 (GND), U2.E1 (GND_RF), U2.E2 (GNDANA), U2.F2 (GND_RF), U2.G2 (GND_RF), U2.G3 (GND_RF), U2.G5 (GND_RF), U2.G6 (GND_RF), U2.G7 (GND_RF), U2.H5 (GND_RF), U3.2 (GND), U3.7 (GND), U3.8 (GND), U3.10 (GND), U3.12 (GND), U3.13 (EP), XC1.2 (GND)
unnamed: C7.1, C8.1, U2.H2 (VR_ANA)
unnamed: C9.1, U2.H4 (VR_DIG)
unnamed: C14.1, U2.A5 (VDDCORE)
unnamed: C16.1, C21.1, L5.2, U3.1 (J1)
unnamed: C16.2, C20.1, L4.2, L5.1
unnamed: C17.1, C19.1, L4.1
unnamed: C17.2, C18.1, L3.2, L6.1
unnamed: C22.1, C23.1, L7.1
unnamed: C22.2, U3.9 (J2)
unnamed: C26.1, C27.2, C31.1, L10.2, L11.1
unnamed: C26.2, C30.1, L9.2, L10.1
unnamed: C27.1, C32.1, L11.2, U3.3 (J3)
unnamed: C28.1, L9.1
unnamed: C34.1, JP1.2 (C), U3.6 (VDD)
PA04_S0_UART_TX: U1.27 (PA04), U2.D3 (PA04)
PA05_S0_UART_RX: U1.26 (PA05), U2.C4 (PA05)
PA06_ADC6: JP1.3 (B), U1.2 (PA06), U2.E3 (PA06)
PA07_ADC7: U1.4 (PA07), U2.F3 (PA07)
PA08_GPIO: U1.6 (PA08), U2.F4 (PA08)
PA14_GPIO: U1.12 (PA14), U2.F8 (PA14)
PA15_GPIO: U1.11 (PA15), U2.G8 (PA15)
PA16_S1_I2C_SDA: U1.9 (PA16), U2.F7 (PA16)
PA17_S1_I2C_SCL: U1.8 (PA17), U2.E6 (PA17)
PA18_PWM_T0_W2: U1.10 (PA18), U2.E7 (PA18)
PA19_PWM_T0_W3: U1.13 (PA19), U2.E8 (PA19)
PA22_GPIO: U1.14 (PA22), U2.D8 (PA22)
PA23_S5_SPI_SS: U1.15 (PA23), U2.D7 (PA23)
PA27_GPIO: U1.3 (PA27), U2.E4 (PA27)
PA28_GPIO: U1.24 (PA28), U2.C6 (PA28)
PA30_SWDCLK: U1.21 (PA30), U2.C5 (PA30)
PA31_SWDIO: U1.22 (PA31), U2.D5 (PA31)
PA_BOOST: L3.1, U2.F1 (PA_BOOST)
PB02_S5_SPI_MISO: U1.25 (PB02), U2.B4 (PB02)
PB22_S5_SPI_MOSI: U1.5 (PB22), U2.E5 (PB22)
PB23_S5_SPI_SCK: U1.7 (PB23), U2.C7 (PB23)
RFI_HF: L7.2, U2.A1 (RFI_HF)
RFO_HF: C28.2, C29.1, L8.2, U2.B1 (RFO_HF)
TCXO_PWR: C35.1, U2.F5 (PA09), XC1.4 (VDD)
TXRX_RF: U2.D2 (RXTX), U3.5 (V2)
USB_N: U1.17 (USB_N), U2.B8 (PA24)
USB_P: U1.16 (USB_P), U2.C8 (PA25)
VDD: C3.1, C4.2, C5.1, C13.2, FB1.2, R1.1, U1.19 (VDD), U2.A7 (VDDIN), U2.A8 (VDDIO2), U2.G4 (VDDIO1), U2.H8 (VBAT_DIG)
VDDA: C1.1, C2.1, C6.1, C10.1, C11.1, C12.1, FB1.1, JP1.1 (A), U2.C1 (VBAT_RF), U2.C2 (VDDANA), U2.H3 (VBAT_ANA)
VR_PA: C24.1, C25.1, L6.2, L8.1, U2.D1 (VR_PA)
XIN32: C36.1, U2.A3 (PA00), Y1.1
XOUT32: C37.1, U2.A4 (PA01), Y1.2
XTA: U2.H6 (XTA), XC1.3 (OUTPUT)
~RESET: C15.1, R1.2, U1.20 (~RST), U2.B6 (~RESET)

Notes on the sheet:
PSU in Linear Mode
1.8-3.6 V
1.8-3.5 V
32MHz
915 MHz Tx Matching
868 MHz Tx Matching
868/915 MHz Rx Matching

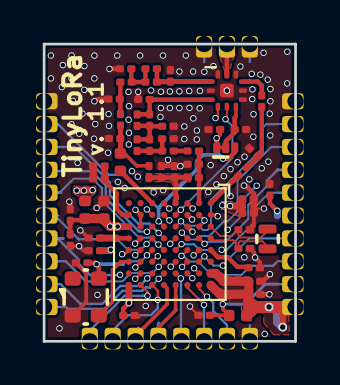
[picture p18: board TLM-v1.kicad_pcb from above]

Board: 4 copper layers, 14.0 x 16.5 mm, 54 parts (0 on the bottom side), 52 nets.

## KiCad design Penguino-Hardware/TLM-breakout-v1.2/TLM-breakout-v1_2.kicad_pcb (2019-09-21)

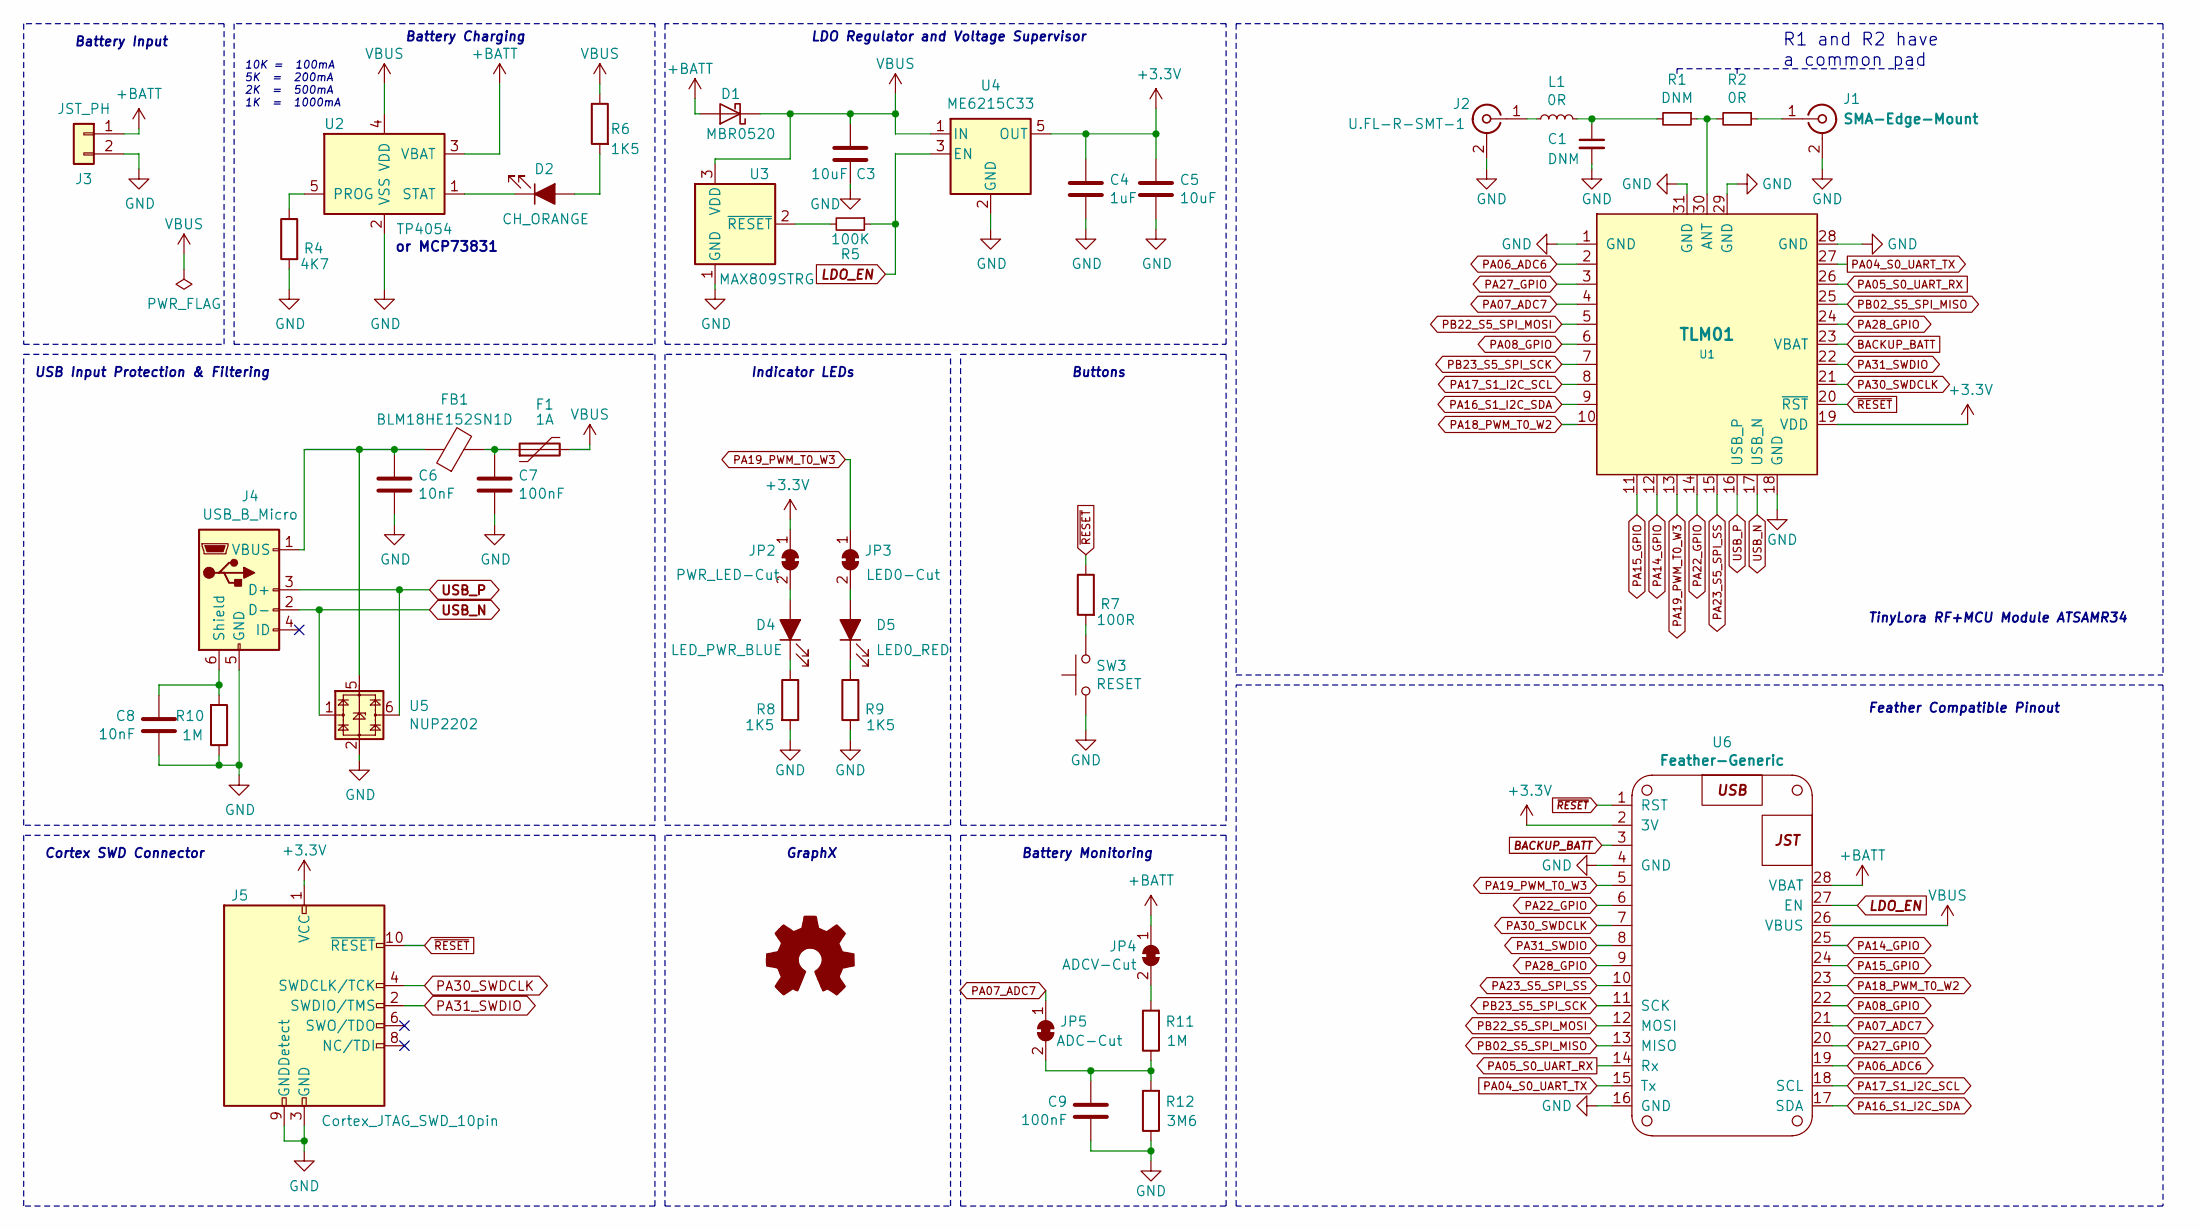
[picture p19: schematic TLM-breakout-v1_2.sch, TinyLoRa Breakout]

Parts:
C1: DNM; C_0402_1005Metric
C3, C5: 10uF; C_0603_1608Metric
C4: 1uF; C_0603_1608Metric; MPN CC0603KRX7R8BB105
C6, C8: 10nF; C_0603_1608Metric; MPN CC0603KRX7R9BB103
C7, C9: 100nF; C_0603_1608Metric; MPN CC0603KRX7R9BB104
D1: MBR0520; D_SOD-123; MPN MBR0520
D2: CH_ORANGE; LED_0603_1608Metric
D4: LED_PWR_BLUE; LED_0603_1608Metric
D5: LED0_RED; LED_0603_1608Metric
F1: 1A; Fuse_0805_2012Metric; MPN 0805L110SLYR
FB1: BLM18HE152SN1D; L_0603_1608Metric; MPN BLM18HE152SN1D
J1: SMA-Edge-Mount; SMA_J_P_X_ST_EM1_EdgeMount; MPN SMA-J-P-H-ST-EM1
J2: U.FL-R-SMT-1; U.FL_Hirose_U.FL-R-SMT-1_Vertical; MPN U.FL-R-SMT-1(80)
J3: JST_PH; JST_PH_S2B-PH-SM4-TB_1x02-1MP_P2.00mm_Horizontal; MPN S2B-PH-SM4-TB(LF)(SN)
J4: USB_B_Micro; USB_Micro-B_C10418; MPN Pads_Jumpers:USB_Micro-B_C10418
J5: Cortex_JTAG_SWD_10pin; PinHeader_2x05_P1.27mm_Vertical_SMD; MPN FTSH-105-01-F-DV-K
JP2: PWR_LED-Cut; SolderJumper-2_P1.3mm_Bridged_RoundedPad1.0x1.5mm
JP3: LED0-Cut; SolderJumper-2_P1.3mm_Bridged_RoundedPad1.0x1.5mm
JP4: ADCV-Cut; SolderJumper-2_P1.3mm_Bridged_RoundedPad1.0x1.5mm
JP5: ADC-Cut; SolderJumper-2_P1.3mm_Bridged_RoundedPad1.0x1.5mm
L1: 0R; L_0402_1005Metric
R1: DNM; R_0402_1005Metric
R2: 0R; R_0402_1005Metric
R4: 4K7; R_0402_1005Metric
R5: 100K; R_0402_1005Metric
R6, R8, R9: 1K5; R_0402_1005Metric
R7: 100R; R_0402_1005Metric
R10, R11: 1M; R_0402_1005Metric
R12: 3M6; R_0402_1005Metric; MPN RC0402JR-073M6L
SW3: RESET; SW_Push_SKRPACE010; MPN SKRPACE010
U1: TLM01; TLM-01-footprint_w_paste
U2: TP4054; SOT-23-5; MPN TP4054
U3: MAX809STRG; SOT-23; MPN MAX809STRG
U4: ME6215C33; SOT-23-5; MPN ME6215C33
U5: NUP2202; SOT-363_SC-70-6; MPN NUP2202W1T2G
U6: Feather-Generic

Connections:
+3V3: C4.1, C5.1, J5.1 (VCC), JP2.1 (A), U1.19 (VDD), U4.5 (OUT), U6.2 (3V)
+BATT: D1.2 (A), J3.1, JP4.1 (A), U2.3 (VBAT), U6.28 (VBAT)
BACKUP_BATT: U1.23 (VBAT), U6.3
GND: C1.2, C3.2, C4.2, C5.2, C6.2, C7.2, C8.1, C9.1, J1.2 (Ext), J2.2 (Ext), J3.2, J4.5 (GND), J5.3 (GND), J5.5 (GND), J5.9 (GNDDetect), R4.2, R8.2, R9.2, R10.1, R12.1, SW3.1, U1.1 (GND), U1.18 (GND), U1.28 (GND), U1.29 (GND), U1.31 (GND), U2.2 (VSS), U3.1 (GND), U4.2 (GND), U5.2, U6.4 (GND), U6.16 (GND)
LDO_EN: R5.1, U4.3 (EN), U6.27 (EN)
unnamed: C1.1, L1.2, R1.2
unnamed: C6.1, FB1.1, J4.1 (VBUS), U5.5
unnamed: C7.1, F1.1, FB1.2
unnamed: C8.2, J4.6 (Shield), R10.2
unnamed: C9.2, JP5.2 (B), R11.1, R12.2
unnamed: D2.1 (K), U2.1 (STAT)
unnamed: D2.2 (A), R6.2
unnamed: D4.1 (K), R8.1
unnamed: D4.2 (A), JP2.2 (B)
unnamed: D5.1 (K), R9.1
unnamed: D5.2 (A), JP3.2 (B)
unnamed: J1.1 (In), R2.1
unnamed: J2.1 (In), L1.1
unnamed: JP4.2 (B), R11.2
unnamed: R1.1, R2.2, U1.30 (ANT)
unnamed: R4.1, U2.5 (PROG)
unnamed: R5.2, U3.2 (~RESET)
unnamed: R7.2, SW3.2
PA04_S0_UART_TX: U1.27, U6.15 (Tx)
PA05_S0_UART_RX: U1.26, U6.14 (Rx)
PA06_ADC6: U1.2, U6.19
PA07_ADC7: JP5.1 (A), U1.4, U6.21
PA08_GPIO: U1.6, U6.22
PA14_GPIO: U1.12, U6.25
PA15_GPIO: U1.11, U6.24
PA16_S1_I2C_SDA: U1.9, U6.17 (SDA)
PA17_S1_I2C_SCL: U1.8, U6.18 (SCL)
PA18_PWM_T0_W2: U1.10, U6.23
PA19_PWM_T0_W3: JP3.1 (A), U1.13, U6.5
PA22_GPIO: U1.14, U6.6
PA23_S5_SPI_SS: U1.15, U6.10
PA27_GPIO: U1.3, U6.20
PA28_GPIO: U1.24, U6.9
PA30_SWDCLK: J5.4 (SWDCLK/TCK), U1.21, U6.7
PA31_SWDIO: J5.2 (SWDIO/TMS), U1.22, U6.8
PB02_S5_SPI_MISO: U1.25, U6.13 (MISO)
PB22_S5_SPI_MOSI: U1.5, U6.12 (MOSI)
PB23_S5_SPI_SCK: U1.7, U6.11 (SCK)
USB_N: J4.2 (D-), U1.17 (USB_N), U5.1
USB_P: J4.3 (D+), U1.16 (USB_P), U5.6
VBUS: C3.1, D1.1 (K), F1.2, R6.1, U2.4 (VDD), U3.3 (VDD), U4.1 (IN), U6.26 (VBUS)
~RESET: J5.10 (~RESET~), R7.1, U1.20 (~RST), U6.1 (RST)

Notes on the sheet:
10K = 100mA 5K = 200mA 2K = 500mA 1K = 1000mA
Battery Input
Battery Charging
LDO Regulator and Voltage Supervisor
USB Input Protection & Filtering
Indicator LEDs
Buttons
TinyLora RF+MCU Module ATSAMR34
Feather Compatible Pinout
Battery Monitoring
GraphX
R1 and R2 have a common pad
Cortex SWD Connector
or MCP73831

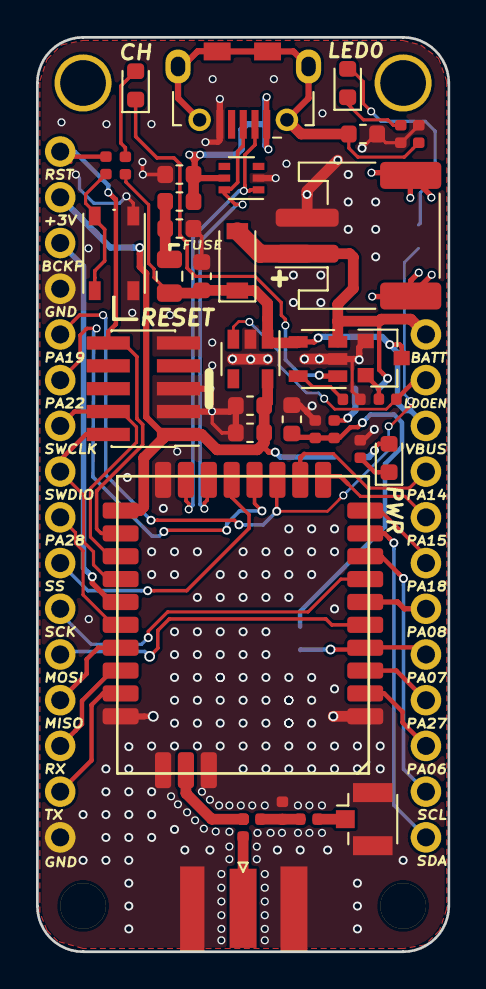
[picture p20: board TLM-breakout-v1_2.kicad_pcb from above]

Board: 2 copper layers, 22.9 x 50.8 mm, 42 parts (0 on the bottom side), 47 nets.

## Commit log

2019-02-27 TLM files added
    Initial commit.
    [TLM-v1-B.Mask.gbs, TLM-v1-B.Paste.gbp, TLM-v1-B.SilkS.gbo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]
2019-02-28 TinyLora Breakout
    TinyLora Breakout files added
    [TLM-breakout-v1.kicad_pcb, TLM-breakout-v1.sch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]
2019-03-06 TLM01-v.1.1 added
    Minor bug fixes and layout improvements
    [TLM-breakout-v1.kicad_pcb, TLM-breakout-v1.sch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]
2019-03-14 BOMs added
    BOMs for TinyLoRa and its breakout added
    [TLM-breakout-v1-B.Mask.gbs, TLM-breakout-v1-B.Paste.gbp, TLM-breakout-v1-B.SilkS.gbo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]
2019-06-22 tlm-v1.1 files corrected
    added schematic
    [TLM-v1-B.Mask.gbs, TLM-v1-B.Paste.gbp, TLM-v1-B.SilkS.gbo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]
2019-06-22 links corrected
    [TLM-breakout-v1-B.Mask.gbs, TLM-breakout-v1-B.Paste.gbp, TLM-breakout-v1-B.SilkS.gbo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]
2019-06-22 readme updated
    [TLM-breakout-v1.csv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]
2019-09-21 ver 1.2 files added
    [TLM-breakout-v1_2-B_Mask.gbs, TLM-breakout-v1_2-B_Paste.gbp, TLM-breakout-v1_2-B_SilkS.gbo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]
2019-11-06 minor updates
    [TLM-v1-B.Mask.gbs, TLM-v1-B.Paste.gbp, TLM-v1-B.SilkS.gbo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]
2019-11-06 RAK4260 lib added
    [radk4260-freeCad-2.FCStd, radk4260-freeCad.FCStd, radk4260.kicad_pcb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]
2019-11-06 Folder structure rearranged
    [radk4260-pcb.kicad_pcb, radk4260-pcb.step, rak4260-freeCad-2.FCStd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]
2019-11-06 copy files deleted
    [radk4260-freeCad-2.FCStd, radk4260-freeCad.FCStd, radk4260.kicad_pcb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]
2019-11-06 RAK4260 PCB fix
2019-11-08 Fixed PDF
    [TLM-v1-B.Mask.gbs, TLM-v1-B.Paste.gbp, TLM-v1-B.SilkS.gbo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]
2019-11-09 Minor changes
    [TLM-v1-B.Mask.gbs, TLM-v1-B.Paste.gbp, TLM-v1-B.SilkS.gbo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]
2019-11-09 TinyLoRa 4260 Files added
    Inital version of the RAK4260 Feather breakout added
    [TLM-4260-breakout-v1_0.kicad_pcb, TLM-4260-breakout-v1_0.sch]
2019-11-10 Latest version of TinyLoRa 4260
    Slight layout updates and added BOM
    [BOM-TinyLoRa-Feather-4260-breakout-v1_0.ods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]
2019-11-11 TinyLoRa 4260 slight layout changes
    [TLM-4260-breakout-v1_0-B_Mask.gbs, TLM-4260-breakout-v1_0-B_Paste.gbp, TLM-4260-breakout-v1_0-B_SilkS.gbo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]
2019-11-14 Naming updates
    [BOM-TinyLoRa-Feather-4260-breakout-v1_0.ods, BOM-TinyLoRa-Feather-4260-v1_0.ods, BOM-TinyLoRa-Feather-4260-v1_0.xlsx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]
2019-11-20 Naming updates
    Project name is now Penguino
    [BOM-TinyLoRa-Feather-4260-v1_0.ods, BOM-TinyLoRa-Feather-4260-v1_0.xlsx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]
2019-12-11 Name changes
    [BOM-TinyLoRa-Feather-4260-v1_0.ods, BOM-TinyLoRa-Feather-4260-v1_0.xlsx, Penguino-Feather-4260-v1_0.kicad_pcb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]
2019-12-16 Penguino 4260 v1.1 added
    SWD line fix and some layout changes (including Logo)
    [BOM-Penguino-Feather-4260-v1.ods, BOM-Penguino-Feather-4260-v1.xlsx, BOM-Penguino-Feather-4260-v1_0.ods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]
2019-12-16 RAK4260 datasheet pin error
    PA19 and PA18 are swapped
    [Penguino-Feather-4260-v1-B_Mask.gbs, Penguino-Feather-4260-v1-B_Paste.gbp, Penguino-Feather-4260-v1-B_SilkS.gbo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]
2020-01-23 Penguino examples added
    Exampel code for LoRaWAN and RGB LED toggle
2020-04-12 Repo celanup
    Penguino 4260 files are moved to a dedicated repo
    [BOM-Penguino-Feather-4260-v1.ods, BOM-Penguino-Feather-4260-v1.xlsx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]
